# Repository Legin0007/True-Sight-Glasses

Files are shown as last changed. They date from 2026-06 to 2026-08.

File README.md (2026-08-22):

## What this project does
This project looks at people's faces using a small camera attached to the glasses frame. If a face matches an entry in my repository, the system retrieves the file name and plays the audio through a small speaker into my ear. Also I would like to preface this by saying I am using a libary called ESP-WHO and the example code I am using is made by them and modified by me. Also here is the demo video https://youtube.com/shorts/fBa7BR6LM4Y?is=uIni2kENnGARo2fe
# Why I made this
This project was made because I have a poor memory and I often forget peoples names so this is a simple and semi-elegant solution.Other people that may use this are people with memory loss or other memory related illnesses or diseases. 
# Challenges I faced
When I was designing this I went through 3 versions of my build. The first design was replaced because the chip I was using was too big and ended up with 2 separate parts which wasn't optimal so I changed the chip and battery to be smaller and fit on one side but I had to change that because it wasn't compatible with the code so the final design uses a esp32-s3 Eye which led to it being wider than the 2nd design.
## Construction Instructions:
### Sourcing Parts
1.Download the BOM and open it in google sheets or some thing like it.
2.Go through all the links and buy the parts that are required.
3.Download the folder called "3D-Models" download them and print them using your respective slicer.
4.After you source all the parts put them in their respective positions and use the pins to hold them in place.
### Soldering parts
1.Solder the battery positive to B+ and the negative to the B-
2.Solder 2 wires to out- and 1 to out+
3.Solder the out+ wire to one side of the switch and solder 2 wires on the output of the switch
4.Solder one of the positive wires from the switch to the amp SD pin.
5.On the amp make a wire from Vin to SD along with the positive wire.
6.Solder from the amp BCLK to IO21 then then LRC to IO48 then DIN to IO47
7.Solder the one remaining positive and negative wire to the 2 + and - pins on the back of the esp32-s3 eye to provide power to that.
### Flashing the firmware
1.You need to download the folder labeled "Code".
2.Open VS code and go to file and select open folder then go to esp-who\examples\human_face_recognition and click open folder.
3.You need to install ESP-IDF from the link in Resources and select custom install then follow all the steps until it asks for the version which you select 5.5.4 and continue with the installation.
4.Go to VS code and install the ESP-IDF extension.
5.Press F1 and type  ESP-IDF: Open ESP-IDF Terminal then type idf.py reconfigure
6.Press F1 and type  ESP-IDF: Select Port to Use (COM, tty, usbserial)
7.Press F1 and run ESP-IDF: Build, Flash and Start a Monitor
8.Go to the file who_recognition.cpp then you need to find where it says "Hello Amma" and change it out with the first person you will enroll so on and so forth.
## Note
The parts are held in place by having a gap in the main body which is can be filled by a seperate pin which blocks the parts from moving.  
## Bom

| Name | Description | Quanity | Unit Price | Shipping cost |
|---|---|---|---|---|
| Esp32s3-EYE | Camera and for running the code | 1 | 45 | 0 |
| Lipo 3.7V 500mAh battery | For powering all parts of the project | 1 | 8.59 | 3.26 |
| Bone Conduction Speaker  | To play peoples names | 1 | 2.16 | 0 |
| Adafruit Mono Amp | gives the speaker instructions | 1 | 2.64 | 0 |
| On/Off Switch | To enable and disable the power. | 1 | 2.81 | 0 |
| 3.3v ldo regulator | To make the volatage 3.3V | 1 | 1.85 | 0 |
| Soldering iron | To attach wires to other parts | 1 | 2.75 | 0 |
| Solder | Melted metal to attach wires | 1 | 2.91 | 0 |
| Heatshrink Tubing | Can cover wires for safety and looks | 1 | 2.68 | 0 |
| Wires | To connect all electrical parts together | 1 | 1.5 | 0 |
| Wire Stripper | To remove plastic from wires for easy soldering | 1 | 3.43 | 0 |
| TP4056 charging module | To recharge the battery | 1 | 5.99 | 0 |
| Total Cost | The total cost of all items | 1 | 91.24 | 0 |

## Wiring Plan



## Zine



## Render

Nigels First numero 1
True_Sight2

## Cad




## IRL Images

WhatsApp Image 2026-08-18 at 8 24 54 PM (2)

WhatsApp_Image_2026-08-18_at_8 24 54_PM-removebg-preview

## Resources
## Video 

https://youtube.com/shorts/fBa7BR6LM4Y?is=uIni2kENnGARo2fe
Download link 
https://docs.espressif.com/projects/idf-im-ui/en/latest/
ESP-WHO link 
https://developer.espressif.com/blog/2026/05/esp-who-get-started/

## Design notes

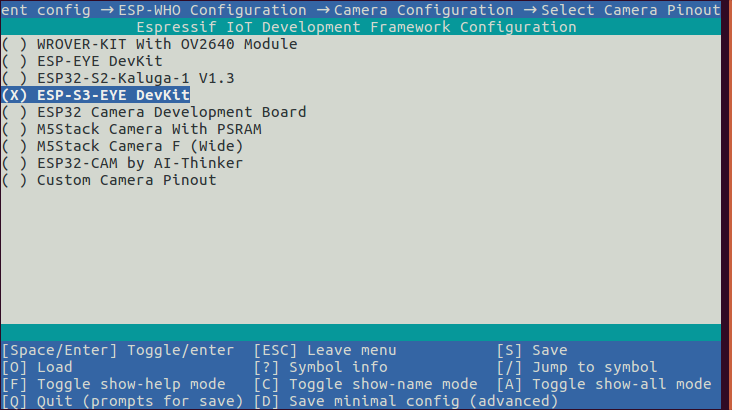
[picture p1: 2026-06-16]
Firmware/Source Code/esp-who/img/esp-who_config_camera_config_select_pinout.png

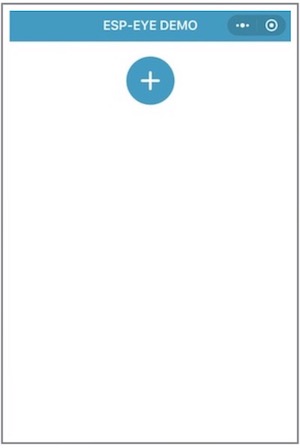
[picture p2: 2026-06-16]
Firmware/Source Code/esp-who/img/esp_eye_Wechat_cross.jpeg

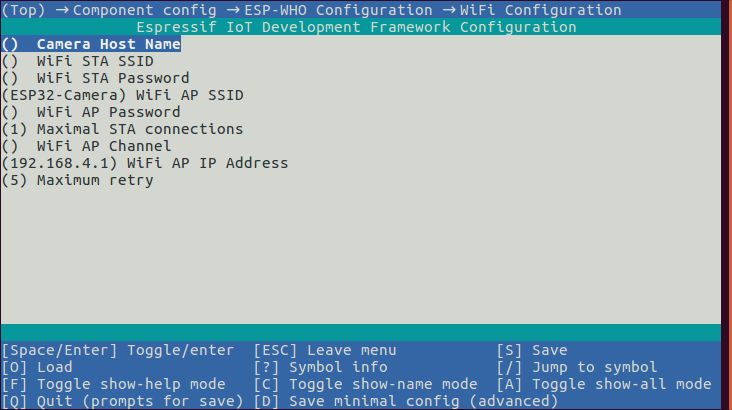
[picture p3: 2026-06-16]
Firmware/Source Code/esp-who/img/esp-who_config_wifi_config.png

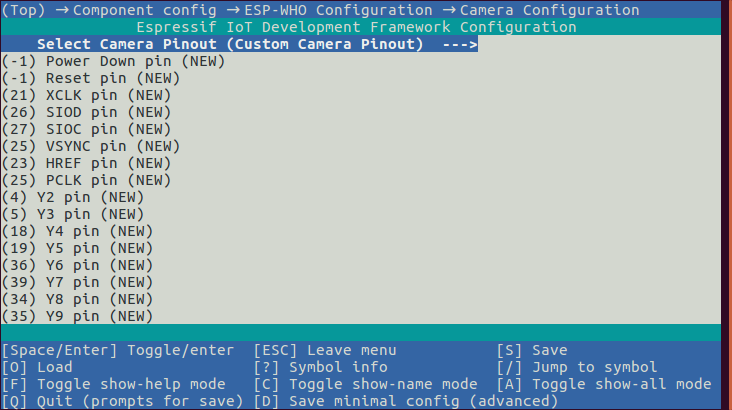
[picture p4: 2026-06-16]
Firmware/Source Code/esp-who/img/esp-who_config_camera_config_custom.png

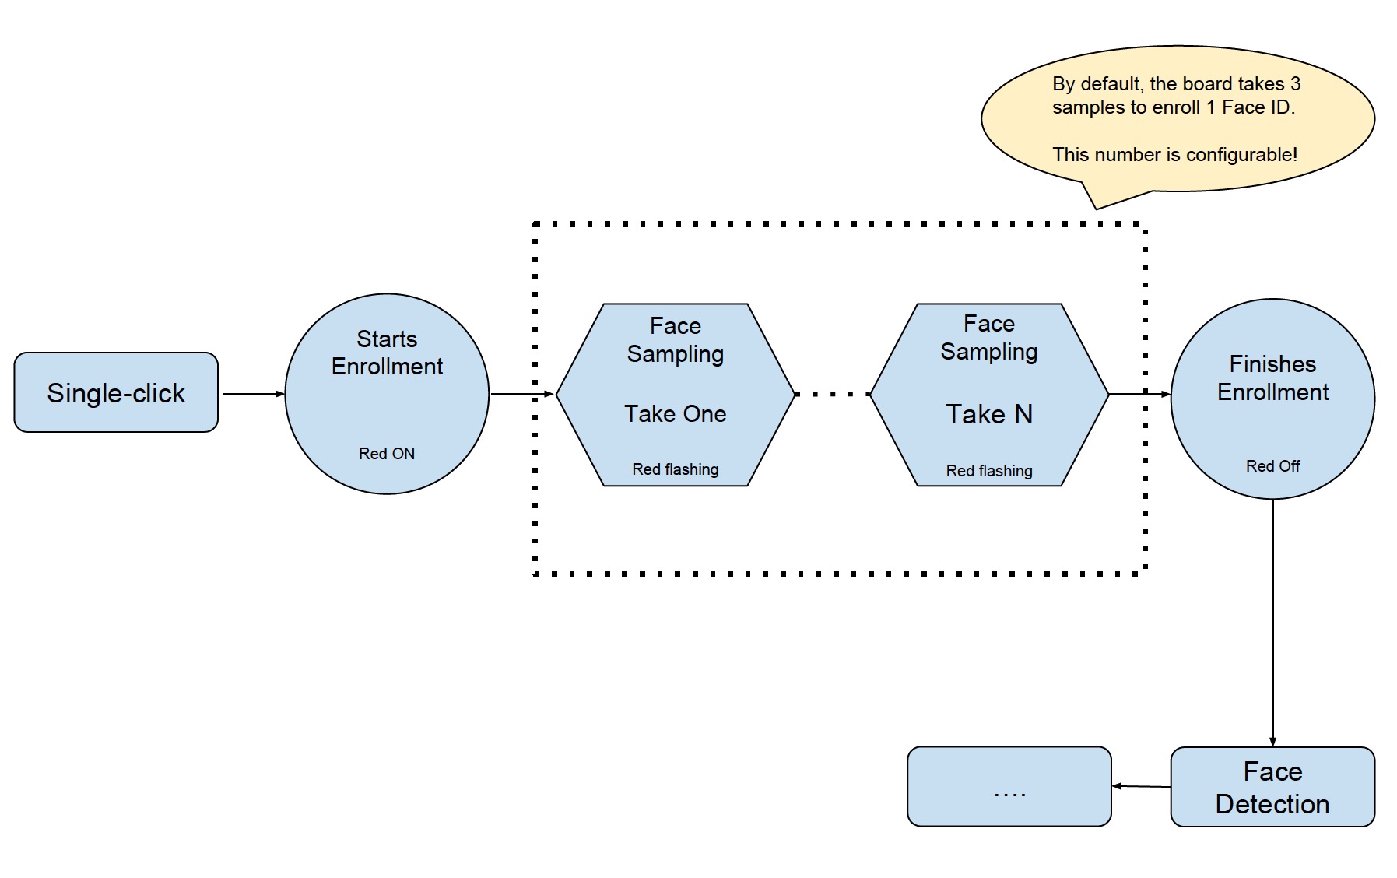
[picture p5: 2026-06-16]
Firmware/Source Code/esp-who/docs/_static/get-started/face_id_enrollment_en.png

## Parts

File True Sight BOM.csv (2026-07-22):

Name | Description | Quanity | Unit Price | Shipping cost | Total Price(With Shipping) | Running Total | Product Links | Notes
Esp32s3-EYE | Camera and for running the code | 1 | 45 | 0 | 45 | 47.98 | https://www.amazon.com/Espressif-ESP32-S3-EYE-Development-Board/dp/B09MS6PH7L | No notes
Lipo 3.7V 500mAh battery | For powering all parts of the project | 1 | 8.59 | 3.26 | 11.85 | 60.62 | https://www.amazon.com/801350-Lithium-Polymer-Battery-Rechargeable/dp/B0C2KSTN7Q | I used amazon for this so I can still have a 500mAh battery and have enough time to build
Bone Conduction Speaker | To play peoples names | 1 | 2.16 | 0 | 2.16 | 62.92 | https://www.aliexpress.us/item/3256809614716496.html?curPageLogUid=sKZA58d3EmLT | This has 5 speakers but I will only be using 1 and all of the others are more expensive with than this pack
Adafruit Mono Amp | gives the speaker instructions | 1 | 2.64 | 0 | 2.64 | 65.73 | https://www.aliexpress.us/item/3256811578520176.html?curPageLogUid=CChBUG9uadbR | This has different positioned pins than the one I have in my wiring plan but it seems that all of them are like this
On/Off Switch | To enable and disable the power. | 1 | 2.81 | 0 | 2.81 | 68.73 | https://www.aliexpress.us/item/3256807801613950.html?curPageLogUid=UmSibAmCQbCK | This product comes in packs of 5 as a minimum but I will only be using one the reason I picked this one is because it is very small
3.3v ldo regulator | To make the volatage 3.3V | 1 | 1.85 | 0 | 1.85 | 70.7 | https://www.aliexpress.us/item/2251801809976592.html?curPageLogUid=MLUUnN5VdEQj | Choose color MINI 3.3V-5PCS AND it is a pack of 5 but I only need one and this is the cheapest
Soldering iron | To attach wires to other parts | 1 | 2.75 | 0 | 2.75 | 73.63 | https://www.aliexpress.us/item/3256806912901320.html?curPageLogUid=uCbCUELEs9hH | I chose the color 7 in 1 blue EU because it is the same price and gives me some extra attachments but if the sale ends I will get the normal version
Solder | Melted metal to attach wires | 1 | 2.91 | 0 | 2.91 | 76.73 | https://www.aliexpress.us/item/3256807971607287.html?curPageLogUid=pQcrFQWQhYSq | Choose type 50 grams
Heatshrink Tubing | Can cover wires for safety and looks | 1 | 2.68 | 0 | 2.68 | 79.59 | https://www.aliexpress.us/item/3256808709374117.html?curPageLogUid=f3gYQKIKKTDA | Choose Color: 127PCS bags Black AND there are 120ish pieces of tubing and I wont use it all but it is the cheapest option availble
Wires | To connect all electrical parts together | 1 | 1.5 | 0 | 1.5 | 81.19 | https://www.aliexpress.us/item/3256804564161230.html?curPageLogUid=cpI5qmmXqlHe | Choose 24 AWG and 5 Meters Color white
Wire Stripper | To remove plastic from wires for easy soldering | 1 | 3.43 | 0 | 3.43 | 84.85 | https://www.aliexpress.us/item/3256811641376358.html?curPageLogUid=Qt32ucLM3CqE | I am not sure if I am allowed to buy this so this may be removed
TP4056 charging module | To recharge the battery | 1 | 5.99 | 0 | 5.99 | 91.24 | https://www.amazon.com/HiLetgo-Lithium-Charging-Protection-Functions/dp/B07PKND8KG | On amazon because I need it to come fast and there is 3 but I am only using 1
Total Cost | The total cost of all items | 1 | 91.24 | 0 | 0

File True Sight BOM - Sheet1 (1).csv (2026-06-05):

Name | Description | Quanity | Unit Price | Shipping cost | Total Price(With Shipping) | Product Links | Running Total | Notes
XIAO ESP32-S3 chip with sense expansion board | Camera and for running the code | 1 | 13 | 6.08 | 19.08 | https://www.seeedstudio.com/XIAO-ESP32S3-Sense-p-5639.html | 19.08 | Will arrive on 06/8/26 and I choose a sooner delivery option because otherwise I wouldn't have been able to finish in time. Used a one time 5$ off coupon
Lipo 3.7V 500mAh battery | For powering all parts of the project | 1 | 8.59 | 3.26 | 11.85 | https://www.amazon.com/801350-Lithium-Polymer-Battery-Rechargeable/dp/B0C2KSTN7Q | 31.72 | I used amazon for this so I can still have a 500mAh battery and have enough time to build
Bone Conduction Speaker | To play peoples names | 1 | 2.16 | 0 | 2.16 | https://www.aliexpress.us/item/3256809614716496.html?curPageLogUid=sKZA58d3EmLT | 34.02 | This has 5 speakers but I will only be using 1 and all of the others are more expensive with than this pack
Adafruit Mono Amp | gives the speaker instructions | 1 | 2.64 | 0 | 2.64 | https://www.aliexpress.us/item/3256811578520176.html?curPageLogUid=CChBUG9uadbR | 36.83 | This has different positioned pins than the one I have in my wiring plan but it seems that all of them are like this
On/Off Switch | To enable and disable the power. | 1 | 2.81 | 0 | 2.81 | https://www.aliexpress.us/item/3256807801613950.html?curPageLogUid=UmSibAmCQbCK | 39.83 | This product comes in packs of 5 as a minimum but I will only be using one the reason I picked this one is because it is very small
3.3v ldo regulator | To make the volatage 3.3V | 1 | 1.85 | 0 | 1.85 | https://www.aliexpress.us/item/2251801809976592.html?curPageLogUid=MLUUnN5VdEQj | 41.8 | Choose color MINI 3.3V-5PCS AND it is a pack of 5 but I only need one and this is the cheapest
Soldering iron | To attach wires to other parts | 1 | 2.75 | 0 | 2.75 | https://www.aliexpress.us/item/3256806912901320.html?curPageLogUid=uCbCUELEs9hH | 44.73 | I chose the color 7 in 1 blue EU because it is the same price and gives me some extra attachments but if the sale ends I will get the normal version
Solder | Melted metal to attach wires | 1 | 2.91 | 0 | 2.91 | https://www.aliexpress.us/item/3256807971607287.html?curPageLogUid=pQcrFQWQhYSq | 47.83 | Choose type 50 grams
Heatshrink Tubing | Can cover wires for safety and looks | 1 | 2.68 | 0 | 2.68 | https://www.aliexpress.us/item/3256808709374117.html?curPageLogUid=f3gYQKIKKTDA | 50.69 | Choose Color: 127PCS bags Black AND there are 120ish pieces of tubing and I wont use it all but it is the cheapest option availble
Wires | To connect all electrical parts together | 1 | 1.5 | 0 | 1.5 | https://www.aliexpress.us/item/3256804564161230.html?curPageLogUid=cpI5qmmXqlHe | 52.29 | Choose 24 AWG and 5 Meters Color white
Wire Stripper | To remove plastic from wires for easy soldering | 1 | 3.43 | 0 | 3.43 | https://www.aliexpress.us/item/3256811641376358.html?curPageLogUid=Qt32ucLM3CqE | 55.95 | I am not sure if I am allowed to buy this so this may be removed

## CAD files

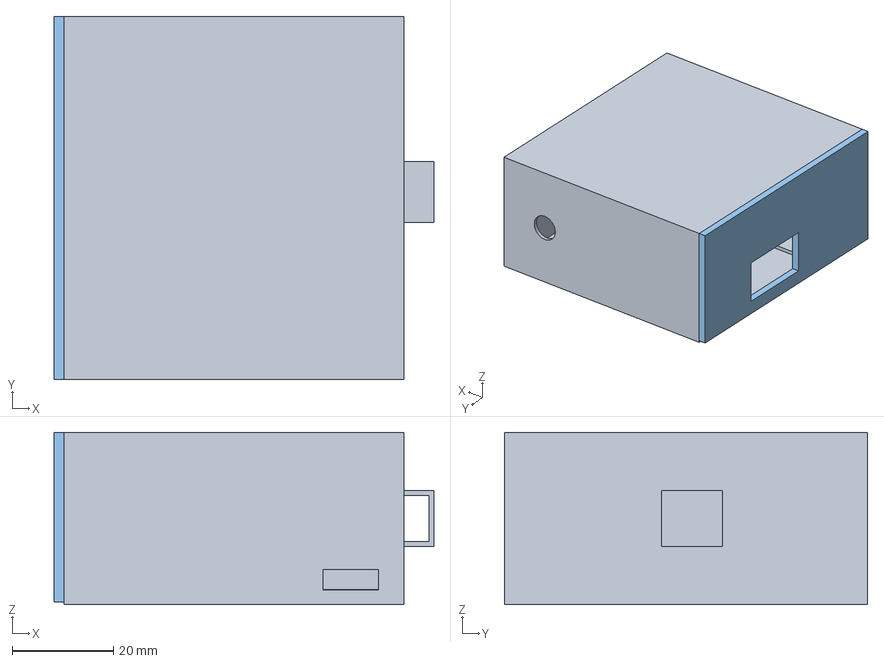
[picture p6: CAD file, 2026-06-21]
Fully Constructed/True_Sight_Fully_Constructed.step
74.9 x 71.6 x 34.0 mm

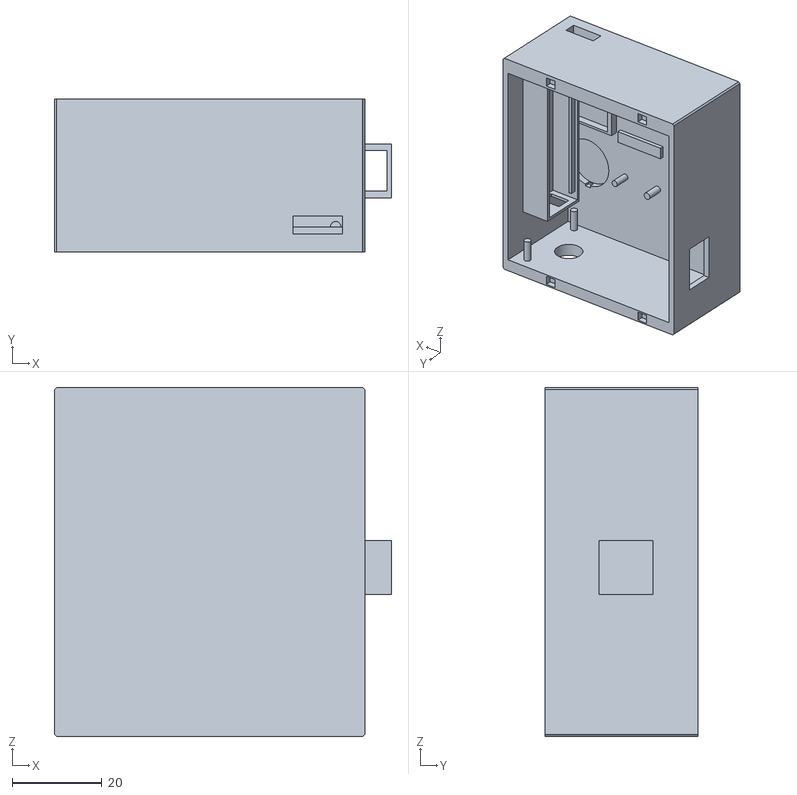
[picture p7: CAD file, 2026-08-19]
CAD/True_Sight_Fixed_Main_Body.stl
74.9 x 34.1 x 77.6

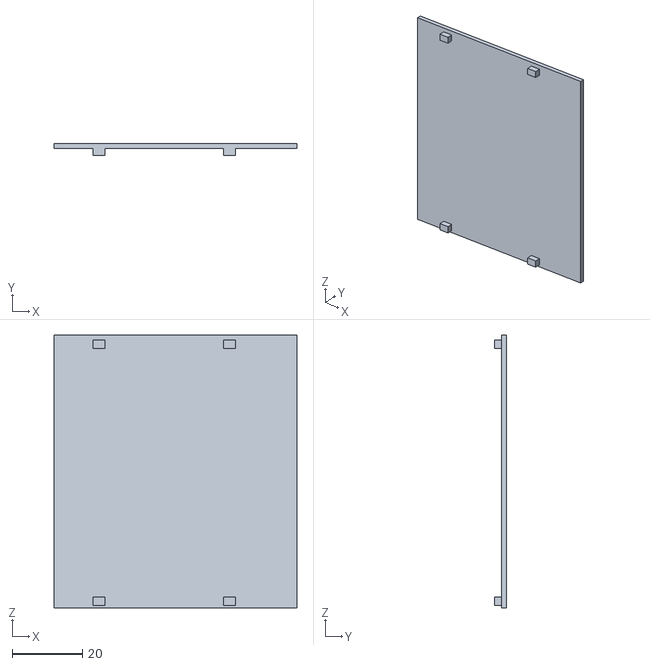
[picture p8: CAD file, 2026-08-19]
CAD/True_Sight_Fixed_Lid.stl
69.0 x 3.50 x 77.6

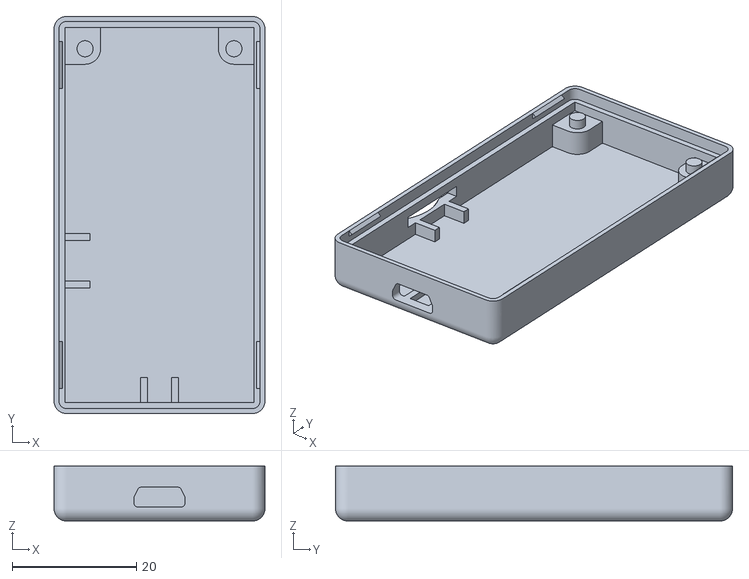
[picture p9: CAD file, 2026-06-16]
Firmware/Source Code/esp-who/docs/_static/get-started/ESP32-S3-EYE_3dpcase_btm.STL
34.0 x 64.0 x 8.86

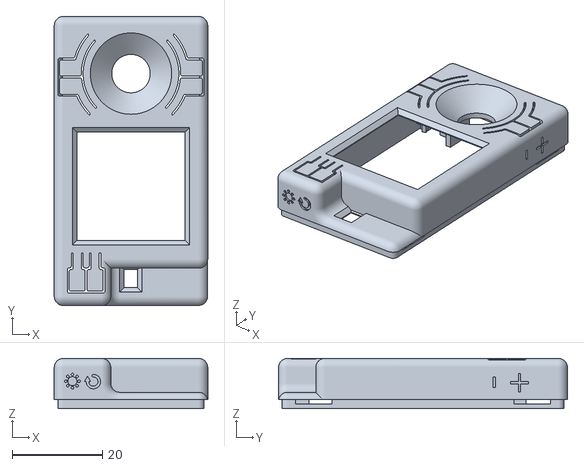
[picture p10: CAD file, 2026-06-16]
Firmware/Source Code/esp-who/docs/_static/get-started/ESP32-S3-EYE_3dpcase_top.STL
34.0 x 64.0 x 11.1

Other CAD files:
Fully Constructed/True_Sight_Fully_Constructed.stl

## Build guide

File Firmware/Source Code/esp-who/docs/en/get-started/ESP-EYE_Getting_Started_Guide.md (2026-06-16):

# ESP-EYE Getting Started Guide

[[中文]](../../zh_CN/get-started/ESP-EYE_Getting_Started_Guide.md)

**Note: The ESP-EYE board has reached End-of-Life (EOL). Please use the [ESP32-S3-EYE](./ESP32-S3-EYE_Getting_Started_Guide.md) as a replacement.**

## What You Need

* 1 × ESP-EYE V2.1 board
* 1 × Micro USB cable
* 1 × PC with Windows, Linux or Mac OS

## Overview

ESP-EYE is an ESP32-based development board that integrates a digital microphone, an 8 MB PSRAM and a 4 MB flash, while also providing an external 2-Megapixel camera. These features make the board ideal for applications relating to face detection, face recognition and speech recognition. Besides, the board can also support image transmission over Wi-Fi and debugging through a Micro USB port, which enables the development of advanced AI solutions.

## Hardware Preparation

The list and figure below describe the key components, interfaces and functions of the ESP-EYE development board:

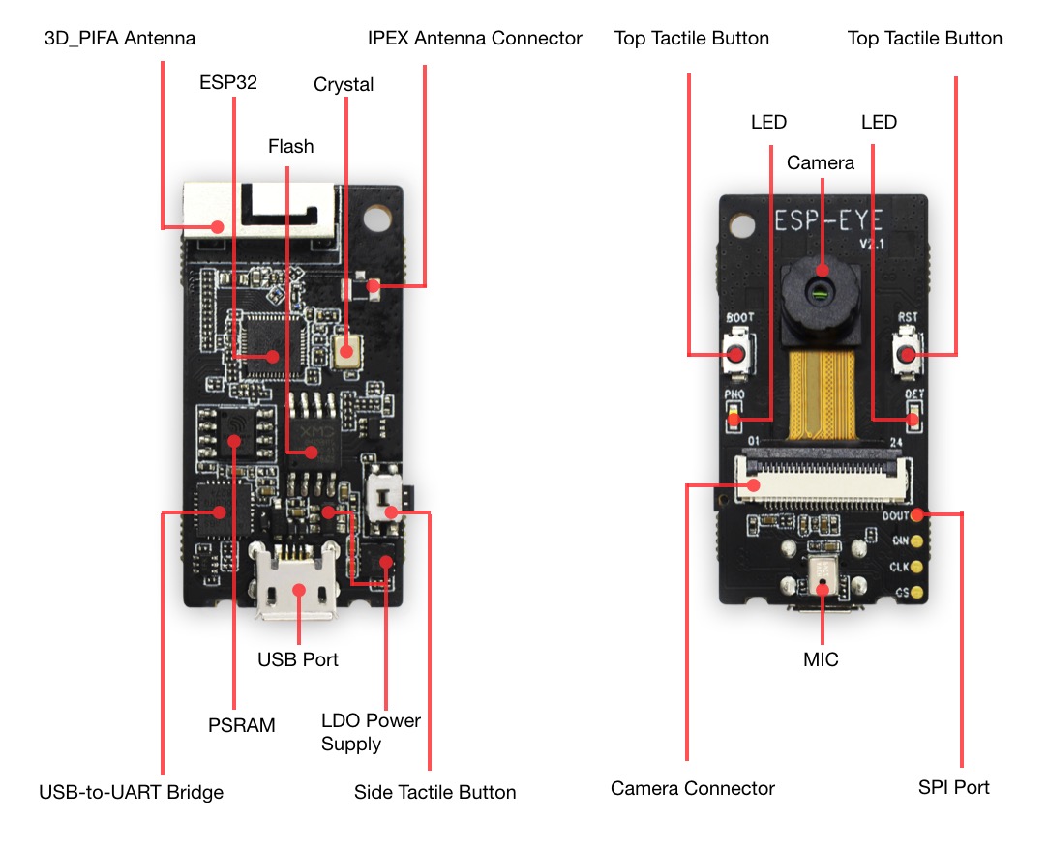
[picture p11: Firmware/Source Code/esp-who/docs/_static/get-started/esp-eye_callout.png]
ESP-EYE image


* **3D_PIFA Antenna**

	A 3D PIFA antenna. With the R14 resistor users can select the external IPEX antenna, whereas with the R15 resistor they can select the 3D antenna.

* **IPEX Connector**

	Used for connecting the external IPEX antenna. With the R14 resistor users can select the external IPEX antenna, whereas with the R15 resistor they can select the 3D antenna.
	
* **ESP32 Chip**

	A 2.4 GHz Wi-Fi and Bluetooth combo chip.
	
* **Crystal Oscillator**

	Provides an external clock to ESP32.

* **Flash & PSRAM**

	Provides memory for storing applications.

* **CP2102 USB-to-UART Chip**

	Converts the USB signals to UART signals.

* **USB Port**

	Provides power supply to the whole system.

* **LDO Power Supply**

	Provides the required power supply to the ESP32 chip, camera and LED indicators.

* **Side Tactile Button**

	A function key.

* **Top Tactile Button**

	Reset/Boot button. We recommend that you do not configure this button for other uses.

* **LED Indicators**

	The board has a red and a white indicator. Different flashing combinations of the red and white indicators reflect the different statuses of the board, e.g. waking up, networking, face detection, face recognition, face enrollment and face recognition.

* **Camera**

	An external 2-Megapixel camera module for face detection, face recognition and Face ID enrollment.

*  **Camera Connector**

	Used for connecting the external camera.

* **MIC**

	A digital microphone for voice control functions.

* **SPI Port**

	A reserved port for data transmission.

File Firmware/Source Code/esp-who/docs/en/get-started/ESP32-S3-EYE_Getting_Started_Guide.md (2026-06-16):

# ESP32-S3-EYE v2.2 <!-- omit in toc -->

[[中文]](../../zh_CN/get-started/ESP32-S3-EYE_Getting_Started_Guide.md)

- [1. Getting Started](#1-getting-started)
  - [1.1. Overview](#11-overview)
  - [1.2. Comparison with ESP-EYE](#12-comparison-with-esp-eye)
  - [1.3. Block Diagram](#13-block-diagram)
  - [1.4. Components on the ESP32-S3-EYE-MB Main Board](#14-components-on-the-esp32-s3-eye-mb-main-board)
  - [1.5. Components on the ESP32-S3-EYE-SUB Sub Board](#15-components-on-the-esp32-s3-eye-sub-sub-board)
  - [1.6. Contents and Packaging](#16-contents-and-packaging)
    - [1.6.1. Retail Orders](#161-retail-orders)
    - [1.6.2. Wholesale Orders](#162-wholesale-orders)
  - [1.7. Default Firmware and Function Test](#17-default-firmware-and-function-test)
- [2. Start Application Development](#2-start-application-development)
  - [2.1. Required Hardware](#21-required-hardware)
  - [2.2. Optional Hardware](#22-optional-hardware)
  - [2.3. Hardware Setup](#23-hardware-setup)
  - [2.4. Software Setup](#24-software-setup)
- [3. Hardware Reference](#3-hardware-reference)
  - [3.1. Notes on GPIO Allocations](#31-notes-on-gpio-allocations)
  - [3.2. Independent Module and Camera Power Supply](#32-independent-module-and-camera-power-supply)
- [4. Hardware Revision Details](#4-hardware-revision-details)
  - [4.1. Revision History](#41-revision-history)
  - [4.2. known Issues](#42-known-issues)
- [5. Related Documents](#5-related-documents)
  - [5.1. Datasheet](#51-datasheet)
  - [5.2. Schematic](#52-schematic)
  - [5.3. PCB Layout](#53-pcb-layout)
  - [5.4. Dimensions](#54-dimensions)
  - [5.5. 3D Printed Case](#55-3d-printed-case)

This user guide will help you get started with ESP32-S3-EYE v2.2 and will also provide more in-depth information.

> **Notice**
>
> If you use ESP32-S3-EYE v2.1, please follow this guide. The differences between v2.2 and v2.1 are described in Section [Hardware Revision Details](#4-hardware-revision-details).

The ESP32-S3-EYE is a small-sized AI development board produced by [Espressif](https://espressif.com). It is based on the [ESP32-S3](https://www.espressif.com/en/products/socs/esp32-s3) SoC and [ESP-WHO](https://github.com/espressif/esp-who), Espressif’s AI development framework. It features a 2-Megapixel camera, an LCD display, and a microphone, which are used for image recognition and audio processing. ESP32-S3-EYE offers plenty of storage, with an 8 MB Octal PSRAM and a 8 MB flash. It also supports image transmission via Wi-Fi and debugging through a Micro-USB port. With ESP-WHO, you can develop a variety of AIoT applications, such as smart doorbell, surveillance systems, facial recognition time clock, etc.

<center>

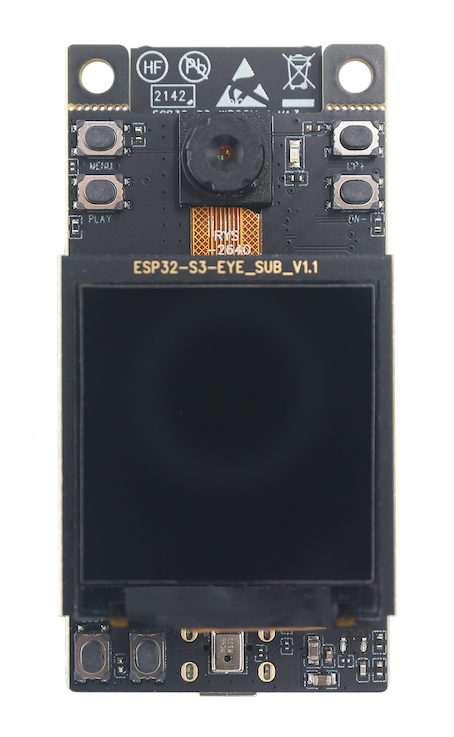
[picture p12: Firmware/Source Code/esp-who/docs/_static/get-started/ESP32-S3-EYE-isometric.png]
ESP32-S3-EYE
|  | 
|:--:| 
|ESP32-S3-EYE|

</center>

The document consists of the following major sections:

-   [Getting started](#1-getting-started): Introduction of the board, block diagram, description of key components, contents and packaging, as well as quick guide to use the board.
-   [Start Application Development](#2-start-application-development): Hardware and software setup instructions to flash firmware onto the board.
-   [Hardware Reference](#3-hardware-reference): More detailed information about the board's hardware.
-   [Hardware Revision Details](#4-hardware-revision-details): Hardware revision history, known issues, and links to user guides for previous versions (if any) of the board.
-   [Related Documents](#5-related-documents): Links to related documentation.

# 1. Getting Started

## 1.1. Overview

The ESP32-S3-EYE board consists of two parts: the main board (ESP32-S3-EYE-MB) that integrates the ESP32-S3-WROOM-1 module, camera, SD card slot, digital microphone, USB port, and function buttons; and the sub board (ESP32-S3-EYE-SUB) that contains an LCD display. The main board and sub board are connected through pin headers.

## 1.2. Comparison with ESP-EYE

The ESP32-S3-EYE has some additional functions comparing to [ESP-EYE](https://github.com/espressif/esp-who/blob/master/docs/en/get-started/ESP-EYE_Getting_Started_Guide.md), an ESP32-based development board. The comparison below covers key differences between the two boards:

| Feature | ESP32-S3-EYE | ESP-EYE | 
|---|---|---|
| Chip embedded | ESP32-S3 | ESP32 |
| PSRAM | 8 MB Octal PSRAM | 8 MB Quad PSRAM |
| Flash | 8 MB flash | 4 MB flash |
| LCD display | Yes | None |
| Accelerometer | Yes | None |
| Alternative power supply  | External battery (optional) | None |
| USB-to-UART bridge | No need. Functionality is provided by ESP32-S3 USB Serial/JTAG interface. | Yes |
| Antenna connector | No need. Antenna is provided by the ESP32-S3-WROOM-1 module. | Yes |

## 1.3. Block Diagram

The block diagram below presents main components of the ESP32-S3-EYE-MB main board (on the left) and the ESP32-S3-EYE-SUB sub board (on the right), as well as the interconnections between components.

<center>

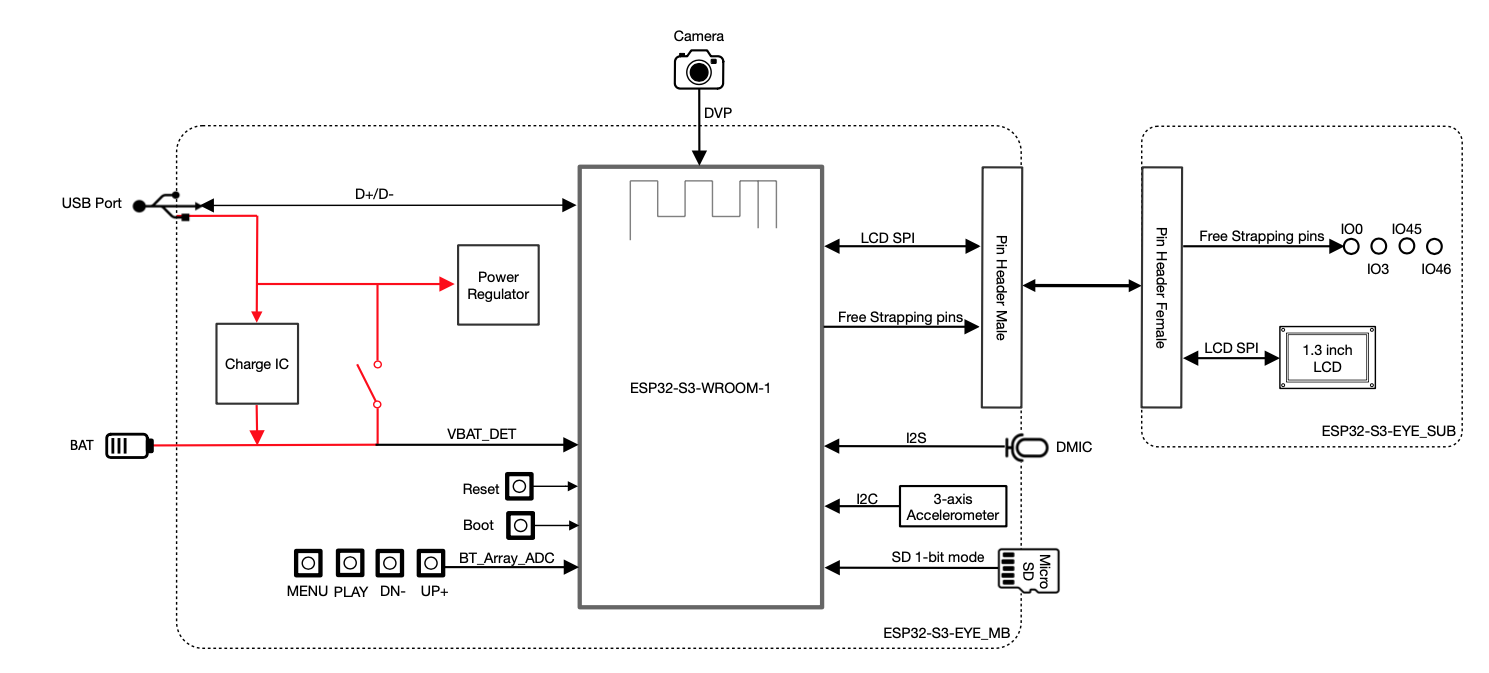
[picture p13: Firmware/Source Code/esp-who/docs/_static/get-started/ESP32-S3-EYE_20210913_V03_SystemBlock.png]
ESP32-S3-EYE Block Diagram
|  | 
|:--:| 
|ESP32-S3-EYE Block Diagram|

</center>

The following sections will describe the key components on the main board and the sub board, respectively.

## 1.4. Components on the ESP32-S3-EYE-MB Main Board

<center>

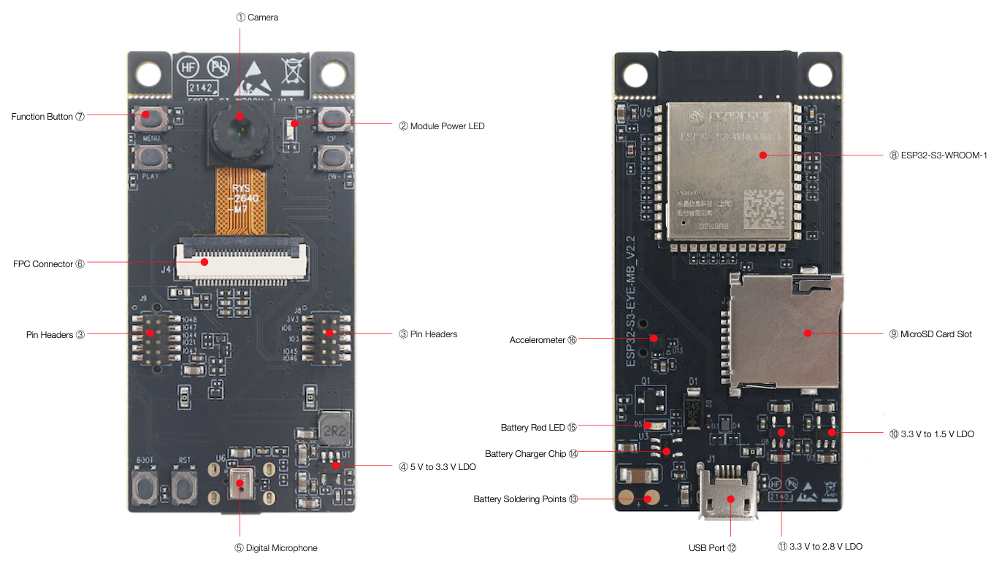
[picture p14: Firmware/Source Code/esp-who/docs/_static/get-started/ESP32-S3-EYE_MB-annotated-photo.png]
ESP32-S3-EYE-MB - front and back
|  | 
|:--:| 
|ESP32-S3-EYE-MB - front and back|

</center>

The key components of the board are described from front view to back view, starting from the camera, in an anti-clockwise direction.

| No. | Key Component | Description |
|-----|----|--|
| 1 | Camera | The camera [OV2640](https://github.com/espressif/esp32-camera) with 2 million pixels has a 66.5° field of view and a maximum resolution of 1600x1200. You can change the resolution when developing applications.|
| 2 | Module Power LED | The LED (green) turns on when USB power is connected to the board. If it is not turned on, it indicates either the USB power is not supplied, or the 5 V to 3.3 V LDO is broken. Software can configure GPIO3 to set different LED statuses (turned on/off, flashing) for different statuses of the board. Note that GPIO3 must be set up in open-drain mode. Pulling GPIO3 up may burn the LED.  |
| 3 | Pin Headers | Connect the female headers on the sub board.|
| 4 | 5 V to 3.3 V LDO | Power regulator that converts a 5 V supply into a 3.3 V output for the module.|
| 5 | Digital Microphone | The digital I2S MEMS microphone features 61 dB SNR and –26 dBFS sensitivity, working at 3.3 V.|
| 6 | FPC Connector | Connects the main board and the sub board. |
| 7 | Function Button | There are six function buttons on the board. Users can configure any functions as needed except for the RST button. |
| 8 | ESP32-S3-WROOM-1 | The ESP32-S3-WROOM-1 module embeds the ESP32-S3R8 chip variant that provides Wi-Fi and Bluetooth 5 (LE) connectivity, as well as dedicated vector instructions for accelerating neural network computing and signal processing. On top of the integrated 8 MB Octal SPI PSRAM offered by the SoC, the module also comes with 8 MB flash, allowing for fast data access. ESP32-S3-WROOM-1U module is also supported.|
| 9 | MicroSD Card Slot | Used for inserting a MicroSD card to expand memory capacity. |
| 10  | 3.3 V to 1.5 V LDO | Power regulator that converts a 3.3 V supply into a 1.5 V output for the camera.|
| 11  | 3.3 V to 2.8 V LDO | Power regulator that converts a 3.3 V supply into a 2.8 V output for the camera.|
| 12  | USB Port | A Micro-USB port used for 5 V power supply to the board, as well as for communication with the chip via GPIO19 and GPIO20.|
  13  | Battery Soldering Points | Used for soldering a battery socket to connect an external Li-ion battery that can serve as an alternative power supply to the board. If you use an external battery, make sure it has built-in protection circuit and fuse. The recommended specifications of the battery: capacity > 1000 mAh, output voltage 3.7 V, input voltage 4.2 V – 5 V.|
| 14  | Battery Charger Chip     | 1 A linear Li-ion battery charger (ME4054BM5G-N) in ThinSOT package. The power source for charging is the **USB Port**.|
| 15  | Battery Red LED          | When the USB power is connected to the board and a battery is not connected, the red LED blinks. If a battery is connected and being charged, the red LED turns on. When the battery is fully charged, it turns off.  |
| 16  | Accelerometer            | Three-axis accelerometer (QMA7981) for screen rotation, etc. |

## 1.5. Components on the ESP32-S3-EYE-SUB Sub Board

<center>

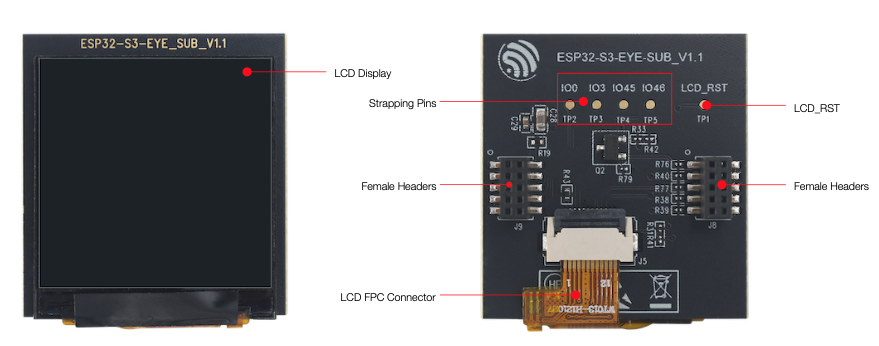
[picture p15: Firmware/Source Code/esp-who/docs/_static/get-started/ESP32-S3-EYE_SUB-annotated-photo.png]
ESP32-S3-EYE-SUB - front and back
|  | 
|:--:| 
|ESP32-S3-EYE-SUB - front and back|

</center>

The key components of the board are described from front view to back view, starting from the LCD display, in an anti-clockwise direction.

| Key Component | Description |
|---|----|
| LCD Display | 1.3” LCD display, connected to ESP32-S3 over the SPI bus. |
| Strapping Pins | Four strapping pins led out from the main board. They can be used as testing points. |
| Female Headers | Used for mounting onto the pin headers on the main board. |
| LCD FPC Connector  | Connects the sub board and the LCD display. |
| LCD_RST | LCD_RST testing point. You can use it to reset the LCD display with control signals.|

## 1.6. Contents and Packaging

### 1.6.1. Retail Orders

If you order a few samples, each board comes in an individual box. Each box contains:

-   1 x ESP32-S3-EYE-MB main board
-   1 x ESP32-S3-EYE-SUB sub board

The main board and sub board are assembled by default.

For retail orders, please go to <https://www.espressif.com/en/company/contact/buy-a-sample>.

### 1.6.2. Wholesale Orders

If you order in bulk, the boards come in large cardboard boxes.

For wholesale orders, please go to <https://www.espressif.com/en/contact-us/sales-questions>.

## 1.7. Default Firmware and Function Test

Each ESP32-S3-EYE board comes with pre-built [default firmware](https://github.com/espressif/esp-who/tree/master/default_bin/esp32-s3-eye) that allows you to test its functions including voice wake-up, voice command recognition, face detection and recognition.

To test the board's functions, you need the following hardware:

-   1 x ESP32-S3-EYE
-   1 x USB 2.0 cable (Standard-A to Micro-B), for USB power supply

Before powering up your board, please make sure that it is in good condition with no obvious signs of damage. Both the main board and the sub board should be firmly connected together. Then, follow the instructions described below:

1. Connect the board to a power supply through the **USB Port** using a USB cable. While the board is powered up, you will notice the following responses:

* The **Module Power LED** turns on for a few seconds, indicating that the default firmware is being loaded. 
* The **Module Power LED** turns off, indicating the default firmware has been loaded. The board enters human face recognition mode by default. 
* The LCD display shows live video streaming.

At this point, the board is ready for further instructions. You can control the board with either function buttons or voice commands. Function button control is described first:

2. Face the camera so whole human face is visible on the screen for the board to detect. Once a human face is detected, the board displays a blue rectangle.
3. Press **MENU** so that the board enters an ID (starting from 1) for a detected human face.
4. Press **UP+** so that the board starts face recognition. Once a face is recognized, the board displays the entered face ID. If it doesn’t know the face, it displays “WHO?”.
5. Press **PLAY** to delete the latest face ID. The board displays "XXX ID(S) LEFT".

To control the board with voice commands, follow the instructions below:

1. Complete step 1 described previously and notice responses from the board.
2. Activate the board with the default English wake word “Hi ESP”. When the wake word is detected, the **Module Power LED** will turn on, indicating that the board is ready for a speech command.
3. Say an English speech command to control the board. Once a speech command is recognized, the **Module Power LED** will blink. The supported English speech commands in face recognition mode are listed below:

| Default English Speech Commands | Response |
|---|---|
| Enter face | The board enters a human face ID. |
| Recognize face | The board displays a recognized human face ID, or "WHO?" for an unrecognized face. |  
| Delete face | The board deletes the latest human face ID entered and displays "XXX ID(S) LEFT". |

4. After waking up the board as described in step 2, you can also switch the board's working mode with speech commands. Once a speech command is recognized, the **Module Power LED** will blink.

| Speech Commands for Different Working Modes | Response |
|---|---|
| Face recognition | The board displays a blue rectangle if a human face is detected. |  
| Motion detection | The board displays a solid blue rectangle in upper-left corner if motion is detected. |
| Display only | The board displays only live video streaming. |
| Stop working | The board does nothing and displays Espressif logo. |

Now you get the first experience with the board. The following sections provide further information about how to flash firmware onto the board, configuration options, related resources, and more.

# 2. Start Application Development

This section provides instructions on how to do hardware/software setup and flash firmware onto the board for application development.

## 2.1. Required Hardware

-   1 x ESP32-S3-EYE
-   1 x USB 2.0 cable (Standard-A to Micro-B), for USB power supply and flashing firmware on to the board
-   1 x Computer running Windows, Linux, or macOS

## 2.2. Optional Hardware

-   1 x MicroSD card
-   1 x Li-ion battery
-   1 x [3D Printed case](#55-3d-printed-case)

> **Notice**
>
> Be sure to use a Li-ion battery that has built-in protection circuit.

## 2.3. Hardware Setup

Prepare the board for loading of the first sample application:
 
Connect the board with the computer through the **USB Port** using a USB cable. The **Module Power LED** should turn on. Assuming that a battery is not connected, the **Battery Red LED** will blink.

Now the board is ready for software setup.

## 2.4. Software Setup

After hardware setup, you can proceed with preparation of development tools. Go to the [guide to ESP-WHO](https://github.com/espressif/esp-who), which will walk you through the following steps:

1. [Get ESP-IDF](https://github.com/espressif/esp-who/#get-esp-idf) which provides a common framework to develop applications for ESP32-S3 in C language.
2. [Get ESP-WHO](https://github.com/espressif/esp-who/#get-esp-who) which is an image processing platform that runs on ESP-IDF.
3. [Run Examples](https://github.com/espressif/esp-who/#run-examples) that are provided by ESP-WHO.

# 3. Hardware Reference

This section provides more detailed information about the board's hardware.

## 3.1. Notes on GPIO Allocations

Except for GPIO3 that can be used to configure LED statuses, all GPIOs of the **ESP32-S3-WROOM-1** module have already been used to control specific components or functions of the board. If you would like to configure any pins yourself, please refer to the schematics provided in Section [Related Documents](#5-related-documents).

## 3.2. Independent Module and Camera Power Supply

The ESP32-S3-EYE board features independent power supplies to the camera and the remaining components. This should reduce noise in the audio signal from module components and improve overall performance of the components.

<center>

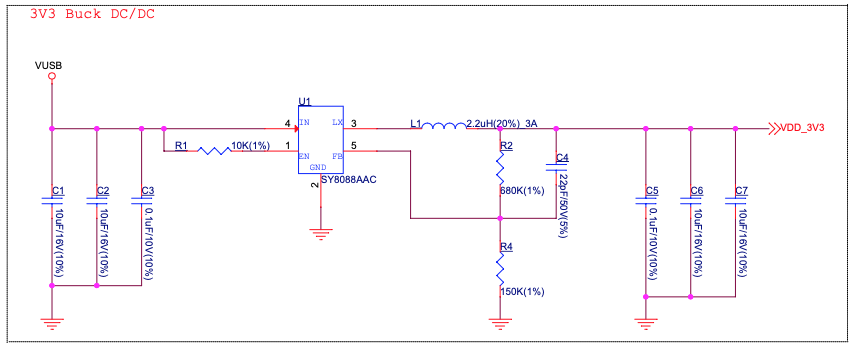
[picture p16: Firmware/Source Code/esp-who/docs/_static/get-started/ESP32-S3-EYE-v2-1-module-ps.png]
ESP32-S3-EYE - Module Power Supply
|| 
|:--:| 
|ESP32-S3-EYE - Module Power Supply|

</center>

<center>

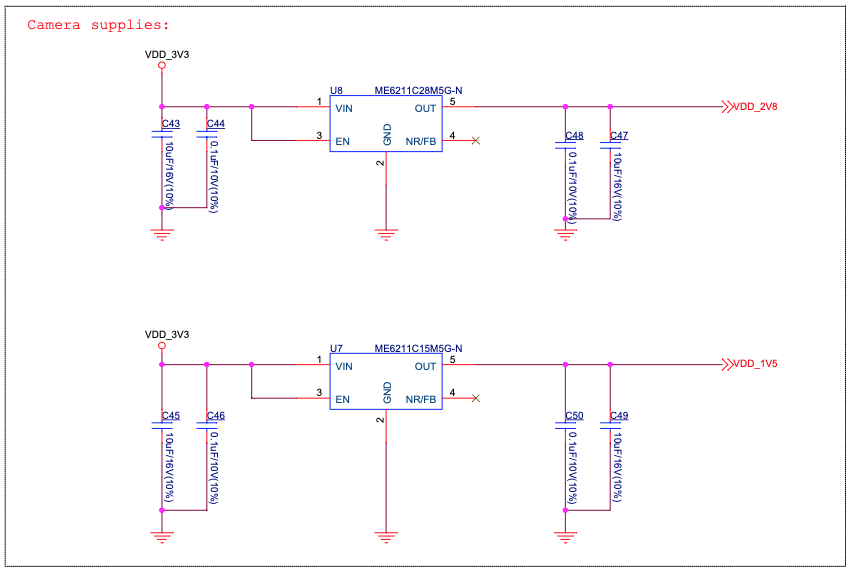
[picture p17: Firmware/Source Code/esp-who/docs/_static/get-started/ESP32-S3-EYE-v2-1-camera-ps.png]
ESP32-S3-EYE - Camera Power Supply
|| 
|:--:| 
|ESP32-S3-EYE - Camera Power Supplies|

</center>

# 4. Hardware Revision Details

## 4.1. Revision History

Compared to ESP32-S3-EYE v2.1, ESP32-S3-EYE v2.2 has two changes in hardware: 1) marking on the main board，2) additional current limiting resistor on the main board; and one change in firmware: additional support for English wake-up word and commands.

Changes in hardware are described in detail below:

1.  Marking on the (back of) main board: ESP32-S3-EYE v2.2 has marking "ESP32-S3-EYE-MB_V2.2" on the main board, while ESP32-S3-EYE v2.1 has marking "ESP32-S3-EYE-MB_V2.1" on the main board.

| ESP32-S3-EYE-MB_V2.2 Marking | ESP32-S3-EYE-MB_V2.1 Marking |
|---|----|
|  ESP32-S3-EYE-MB_V2.2 Marking |ESP32-S3-EYE-MB_V2.1 Marking |

2.  The current limiting resistor R83 is added to the ESP32-S3-EYE v2.2 main board to protect the **Module Power LED** from burning in case GPIO3 is pulled up.

| ESP32-S3-EYE v2.2 with R83 | ESP32-S3-EYE v2.1 Without R83  |
|---|----|
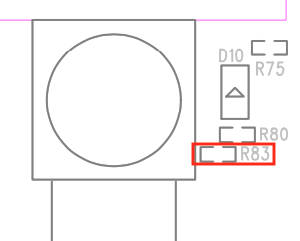
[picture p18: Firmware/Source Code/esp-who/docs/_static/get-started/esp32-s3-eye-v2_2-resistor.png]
ESP32-S3-EYE v2.2 with R83
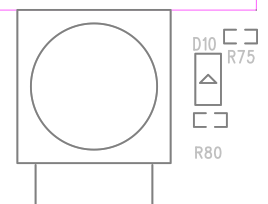
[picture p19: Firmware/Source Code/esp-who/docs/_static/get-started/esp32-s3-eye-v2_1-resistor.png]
ESP32-S3-EYE v2.1 Without R83
|   | |

3.  The **main board schematics**, **main board PCB layout diagrams**, **main board dimension diagrams**, **main board dimension source files** are updated because of the two hardware changes. (See [Related Documents](#5-related-documents)).

## 4.2. known Issues

ESP32-S3-EYE does not have a USB-to-UART bridge, which may cause a problem: If the program flashed onto the board keeps the chip rebooting, you cannot flash more programs onto the board.

In case this issue occurs, you need to:

- Hold down BOOT button and press RST button, then release RST button first, and BOOT button next. In this way, the board enters Firmware Download mode and you can start flashing program onto the board.
- After flashing the program, press RST button to start the program.

# 5. Related Documents

## 5.1. Datasheet

-   [ESP32-S3 Datasheet](https://www.espressif.com/sites/default/files/documentation/esp32-s3_datasheet_en.pdf) (PDF)
-   [ESP32-S3-WROOM-1 & ESP32-S3-WROOM-1U Datasheet](https://www.espressif.com/sites/default/files/documentation/esp32-s3-wroom-1_wroom-1u_datasheet_en.pdf) (PDF)

## 5.2. Schematic

-   [ESP32-S3-EYE-MB v2.2 Main Board Schematic](https://dl.espressif.com/dl/schematics/SCH_ESP32-S3-EYE-MB_20211201_V2.2.pdf) (PDF)
-   [ESP32-S3-EYE-MB v2.1 Main Board Schematic](https://dl.espressif.com/dl/schematics/SCH_ESP32-S3-EYE-MB_20210913_V2.1.pdf) (PDF)
-   [ESP32-S3-EYE-SUB Sub Board Schematic](https://dl.espressif.com/dl/schematics/SCH_ESP32-S3-EYE_SUB_V1.1_20210913.pdf) (PDF)

## 5.3. PCB Layout

-   [ESP32-S3-EYE-MB v2.2 Main Board PCB Layout](https://dl.espressif.com/dl/schematics/PCB_ESP32-S3-EYE_MB_V2.2_20211201.pdf) (PDF)
-   [ESP32-S3-EYE-MB v2.1 Main Board PCB Layout](https://dl.espressif.com/dl/schematics/PCB_ESP32-S3-EYE_MB_V2.1_20210913.pdf) (PDF)
-   [ESP32-S3-EYE-SUB Sub Board PCB Layout](https://dl.espressif.com/dl/schematics/PCB_ESP32-S3-EYE_SUB_V1.1_20210913.pdf) (PDF)

## 5.4. Dimensions

-   [ESP32-S3-EYE-MB v2.2 Main Board Front Dimensions](https://dl.espressif.com/dl/schematics/DXF_ESP32-S3-EYE_MB_top_V2.2_20211207.pdf) (PDF)
-   [ESP32-S3-EYE-MB v2.1 Main Board Front Dimensions](https://dl.espressif.com/dl/schematics/DXF_ESP32-S3-EYE_MB_top_V2.1_20211111.pdf) (PDF)
-   [ESP32-S3-EYE-MB v2.2 Main Board Back Dimensions](https://dl.espressif.com/dl/schematics/DXF_ESP32-S3-EYE_MB_Bottom_V2.2_20211207.pdf) (PDF)
-   [ESP32-S3-EYE-MB v2.1 Main Board Back Dimensions](https://dl.espressif.com/dl/schematics/DXF_ESP32-S3-EYE_MB_Bottom_V2.1_20211111.pdf) (PDF)
-   [ESP32-S3-EYE-SUB Sub Board Dimensions](https://dl.espressif.com/dl/schematics/DXF_ESP32-S3-EYE_SUB_V1.1_20211111.pdf) (PDF)
-   [ESP32-S3-EYE-MB v2.2 Main Board Front Dimensions Source File](https://dl.espressif.com/dl/schematics/DXF_ESP32-S3-EYE_MB_top_V2.2_20211207.dxf) (DXF) - You can view it with [Autodesk Viewer](https://viewer.autodesk.com/) online
-   [ESP32-S3-EYE-MB v2.1 Main Board Front Dimensions Source File](https://dl.espressif.com/dl/schematics/DXF_ESP32-S3-EYE_MB_top_V2.1_20211111.dxf) (DXF) - You can view it with [Autodesk Viewer](https://viewer.autodesk.com/) online
-   [ESP32-S3-EYE-MB v2.2 Main Board Back Dimensions Source File](https://dl.espressif.com/dl/schematics/DXF_ESP32-S3-EYE_MB_Bottom_V2.2_20211207.dxf) (DXF) - You can view it with [Autodesk Viewer](https://viewer.autodesk.com/) online
-   [ESP32-S3-EYE-MB v2.1 Main Board Back Dimensions Source File](https://dl.espressif.com/dl/schematics/DXF_ESP32-S3-EYE_MB_Bottom_V2.1_20211111.dxf) (DXF) - You can view it with [Autodesk Viewer](https://viewer.autodesk.com/) online
-   [ESP32-S3-EYE-SUB Sub Board Dimensions Source File](https://dl.espressif.com/dl/schematics/DXF_ESP32-S3-EYE_SUB_V1.1_20211111.dxf) (DXF) - You can view it with [Autodesk Viewer](https://viewer.autodesk.com/) online

## 5.5. 3D Printed Case

The following 3D model is a two-part case you can 3D print for your ESP32-S3-EYE. Do note that with all 3D Printed products, there will be a variance in tolerance and fitting. Your success may vary.

- [ESP32-S3-EYE Top Case](../../_static/get-started/ESP32-S3-EYE_3dpcase_top.STL)
- [ESP32-S3-EYE Bottom Case](../../_static/get-started/ESP32-S3-EYE_3dpcase_btm.STL)

<center>

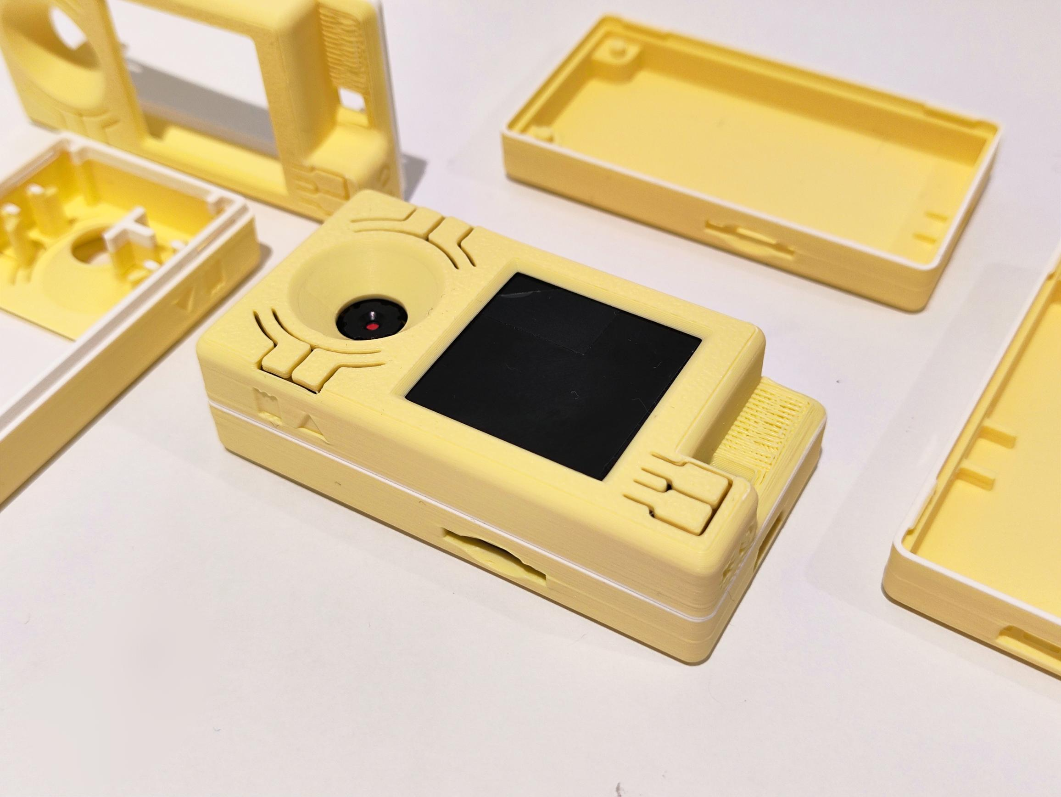
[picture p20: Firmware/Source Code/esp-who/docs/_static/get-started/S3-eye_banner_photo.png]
ESP32-S3-EYE - Case 3D printed on BambuLab P1S
|| 
|:--:| 
|ESP32-S3-EYE - Case 3D printed on [BambuLab P1S](https://bambulab.com/en/p1)|

</center>

For further design documentation for the board, please contact us at [<sales@espressif.com>](sales@espressif.com).

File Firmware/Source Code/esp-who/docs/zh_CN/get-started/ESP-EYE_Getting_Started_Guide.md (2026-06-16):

# ESP-EYE 入门指南

[[EN]](../../en/get-started/ESP-EYE_Getting_Started_Guide.md)

**Note: ESP-EYE 已经停止维护。请使用 [ESP32-S3-EYE](./ESP32-S3-EYE_Getting_Started_Guide.md)。**

## 准备工作

* 1 × ESP-EYE V2.1 开发板
* 1 × Micro USB B 电缆
* 1 × PC（Windows、Linux 或 Mac OS）

## 简介

ESP-EYE 是一款面向人脸识别和语音识别市场的开发板，搭载 ESP32 芯片、200 W 像素摄像头、数字麦克风、8 MB PSRAM 和 4 MB Flash，可满足各种 AI 应用开发需求。此外，该开发板还支持 Wi-Fi 图像传输、Micro USB 调试和供电，可以实现语音唤醒、人脸检测与识别等功能，可协助用户开发高度集成的 AI 解决方案。

## 硬件组成

ESP-EYE 开发板的产品图请见下方：

ESP-EYE image

具体包括以下硬件组成：

* **3D_PIFA Antenna（3D_PIFA 天线）**

	3D PIFA 天线。用户可通过选贴 R14/R15 电阻，选用 3D 天线（选贴 R15）或外接 IPEX 天线（选贴 R14）。

* **IPEX Connector（IPEX 连接器）**

	用于外接 IPEX 天线。用户可通过选贴 R14/R15 电阻，选用 3D 天线（选贴 R15）或外接 IPEX 天线（选贴 R14）。

* **ESP32 Chip（ESP32 芯片）**

	集成 2.4 GHz Wi-Fi 和蓝牙双模的单芯片。

* **Crystal（晶振）**

	ESP32 的外部晶振时钟源。

* **Flash & PSRAM**

	存储芯片，用于储存程序。

* **CP2102 USB-UART Chip（USB 转 UART 芯片）**

	实现 USB 到 UART 的转换功能。

* **USB Port（USB 供电接口）**

	为整个系统供电。

* **LDO Power Supply（LDO 供电芯片）**

	为 ESP32 芯片、摄像头、LED 指示灯等部件提供各自所需的电压。

* **Side Tactile Button（侧面轻触按键）**

	功能按键。

* **Top Tactile Button（正面轻触按键）**

	用于 ESP32 的 RST（复位）、BOOT（下载），不建议设置他用。

* **LED 指示灯**

	红灯和白灯各一个，可用于指示唤醒、联网、人脸检测、人脸录入、人脸识别等不同过程中的状态。

* **Camera（摄像头）**

	实现检测识别等功能。

* **Camera Connector（摄像头连接器）**

	用于外接摄像头模块。

* **MIC（麦克风）**

	数字型麦克风，实现语音控制功能。

* **SPI Port（SPI 接口）**

	预留数据传输接口。

## 软件开发

ESP-EYE 可在 Linux、MacOs、Windows 操作系统中完成软件烧写。目前，必须进行开发环境的工具链配置，详见下方介绍。

### 准备工作

- 阅读 [ESP-IDF编程指南](https://docs.espressif.com/projects/esp-idf/zh_CN/v3.1.1/get-started/index.html)，参考相应章节，配置工具链；
- 准备 Micro USB 线，用于连接 PC 和 ESP-EYE 开发板；
- 选择一款适合开发环境的工具，例如 Terminal (Linux/MacOS) 或 MinGW (Windows) 等。

### 软件获取

打开终端（例如 Linux 环境下的 Terminal），将软件代码克隆到本地：

```
git clone --recursive https://github.com/espressif/esp-who.git 
```

执行以上命令会默认生成一个 `esp-who` 的文件夹。

> 注意不要忘记 `--recursive` 选项。如果你克隆 ESP-IDF 时没有带这个选项，你还需要运进入相应文件夹中，执行以下命令下载相应的子模块：
```
git submodule update --init --recursive
```

### 设置路径

请参考[设置路径](https://docs.espressif.com/projects/esp-idf/zh_CN/v3.1.1/get-started/index.html#get-started-setup-path)章节，将 `IDF_PATH` 设置为 `esp-who/esp-idf`。

### 软件烧写

下面，我们以 Linux 环境为例，介绍向 ESP-EYE 烧写程序的过程：

- 首先将 ESP-EYE 接入 PC，接入即上电；
- 通过命令 `ls /dev/ttyUSB*` 查看开发板是否成功接入 PC。成功接入后，列表将新增类似 `/dev/ttyUSB0` 的信息；
- 进入一个 example 工程文件中，例如 `cd esp-who/examples/single_chip/recognition_solution`；
- 执行 `make defconfig` 进行默认配置；
- 执行 `make menuconfig`，在 `Serial flasher config` 中设置 `Default serial port` 设备名称（与第二步查看的设备名称一致，一般设置为 `/dev/ttyUSB0`），保存退出；
- 执行 `make flash`，进行软件烧写。

### 终端获取日志

下面，我们以 Linux 环境为例，介绍如何查看日志：

- 打开终端；
- 执行 `make monitor`。

> 注意：这个过程会重启开发板。

### 交互功能

ESP-EYE 开发板的工作流程如下图所示：

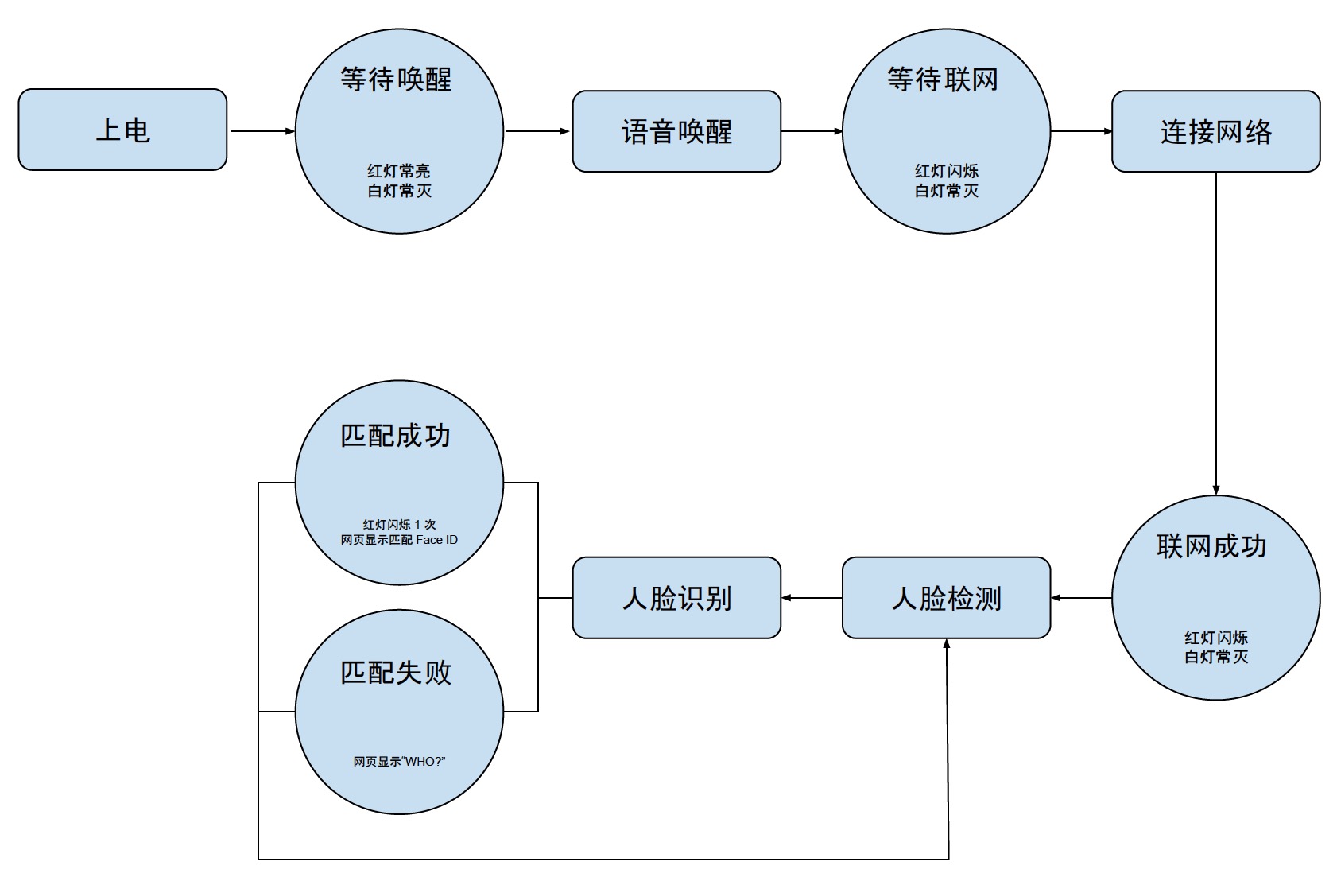
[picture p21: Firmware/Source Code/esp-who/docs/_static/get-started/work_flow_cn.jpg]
esp-eye-workflow


#### 1. 语音唤醒

开发板上电后，会进入“等待唤醒”状态（红灯常亮、白灯常灭），需要用户通过语音进行唤醒。支持“Hi 乐鑫”唤醒，当用户说出“Hi 乐鑫”的唤醒词后，开发板唤醒并进入“等待联网”状态（红灯闪烁，白灯常灭）。此时，用户可进行联网操作。  

#### 2. 连接网络

用户可通过 PC、手机等设备，连接 ESP-EYE 创建的 Wi-Fi 热点。该热点的默认信息如下：

- 用户名：esp-eye-xxxx（xxxx 为设备 MAC 地址）
- 密码：无需密码

用户也可通过如下方式，自行设置用户名和密码：  

- 打开终端；
- 执行 `make menuconfig`，并按照下图进行设置：

	wifi connection

> 注：用户重新设置 Wi-Fi 热点的用户名和密码后，需要重新进行软件烧录。

#### 3. 人脸检测

联网成功后，ESP-EYE 会进行“人脸检测”。用户可以打开浏览器，输入地址 `192.168.4.1/face_stream`，在网页上即可看到实时图像信息。此时，开发板红灯熄灭、白灯常亮。

#### 4. 人脸识别

当开发板检测到人脸时，如已存在录入的 Face ID，则开发板将进行“人脸识别”：

- “人脸识别”匹配成功 -- 开发板红灯闪烁 1 次，网页显示 **HELLO ID XXX**
- “人脸识别”匹配失败 -- 开发板无反应，网页显示 **WHO?**”

否则，开发板仅进行“人脸检测”。此时，若用户希望使用人脸识别功能，则请首先录入至少一个 Face ID。  

#### 5. 人脸录入与删除

在联网成功的前提下，可通过摄像头采集人脸，录入 Face ID。

##### 5.1 录入 Face ID

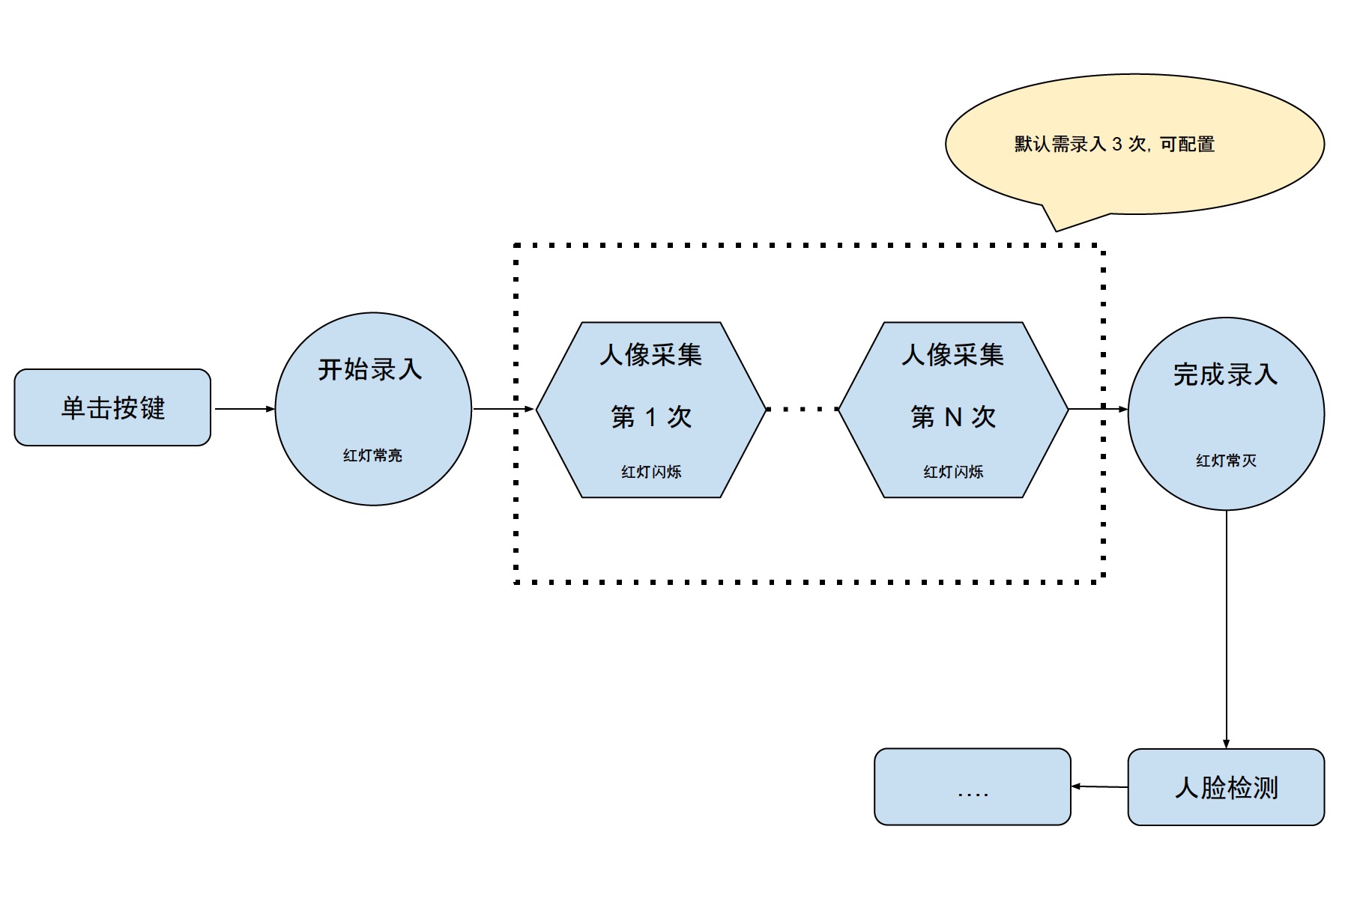
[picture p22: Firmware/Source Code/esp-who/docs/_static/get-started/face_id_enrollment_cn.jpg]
录入 Face ID


- 用户单击侧面轻触按键，可进入“录入 Face ID”（红灯常亮），网页显示: **START ENROLLING**；
- 用户面对摄像头，开始采集人像。每次成功一次采集，开发板将红灯闪烁，网页显示对应的采集次数，比如 **THE 1st SAMPLE** 等。默认情况下，用户每录入一个 Face ID 需要采集 3 次人像（可配置）。在人像采集过程中，如果红灯长时间未闪烁，建议用户调整姿态和角度，然后再试；
- 人像采集完成后，开发板红灯常灭，表明已完成录入该 Face ID。此时，网页显示：**ENROLLED FACE ID xxx**；
- Face ID 录入成功后，系统将返回“人脸检测”。

目前，ESP-EYE 开发板默认可录入 10 个 Face ID（可配置，具体与用户的 flash 内存分配有关）。

##### 5.2 删除 Face ID

- 用户单击表面BOOT按键，进入“删除 FACE ID”；
- 双击后，开发板白灯闪烁，系统将自动删除系统中存在的最早一条 FACE ID，终端显示：**XXX ID(S) LEFT**。

#### 异常情况

当出现“网络断开”或“联网超时”等异常情况时，开发板会回到“等待唤醒”状态。

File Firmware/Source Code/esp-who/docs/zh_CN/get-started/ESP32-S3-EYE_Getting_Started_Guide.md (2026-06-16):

# ESP32-S3-EYE v2.2 <!-- omit in toc -->

[[English Version]](../../en/get-started/ESP32-S3-EYE_Getting_Started_Guide.md)

- [1. 入门指南](#1-入门指南)
  - [1.1. 概述](#11-概述)
  - [1.2. ESP32-S3-EYE 与 ESP-EYE](#12-esp32-s3-eye-与-esp-eye)
  - [1.3. 功能框图](#13-功能框图)
  - [1.4. ESP32-S3-EYE-MB 主板组件](#14-esp32-s3-eye-mb-主板组件)
  - [1.5. ESP32-S3-EYE-SUB 子板组件](#15-esp32-s3-eye-sub-子板组件)
  - [1.6. 内含组件和包装](#16-内含组件和包装)
    - [1.6.1. 零售订单](#161-零售订单)
    - [1.6.2. 批量订单](#162-批量订单)
  - [1.7. 默认固件和功能测试](#17-默认固件和功能测试)
- [2. 开始开发应用](#2-开始开发应用)
  - [2.1. 必备硬件](#21-必备硬件)
  - [2.2. 可选硬件](#22-可选硬件)
  - [2.3. 硬件设置](#23-硬件设置)
  - [2.4. 软件设置](#24-软件设置)
- [3. 硬件参考](#3-硬件参考)
  - [3.1. GPIO 分配](#31-gpio-分配)
  - [3.2. 独立的模组与摄像头供电电路](#32-独立的模组与摄像头供电电路)
- [4. 硬件版本](#4-硬件版本)
  - [4.1. 改版历史](#41-改版历史)
  - [4.2. 已知问题](#42-已知问题)
- [5. 相关文档](#5-相关文档)
  - [5.1. 技术规格书](#51-技术规格书)
  - [5.2. 原理图](#52-原理图)
  - [5.3. PCB 布局图](#53-pcb-布局图)
  - [5.4. 尺寸图](#54-尺寸图)
  - [5.5. 3D打印外壳](#55-3D打印外壳)

本指南将帮助您快速上手 ESP32-S3-EYE v2.2，并提供该款开发板的详细信息。

> **注意**
>
> 如果您使用的是 ESP32-S3-EYE v2.1，请参考本指南。v2.2 相对 v2.1 的变化在[硬件版本](#4-硬件版本)小节中列出。

ESP32-S3-EYE 是[乐鑫](https://www.espressif.com/zh-hans/home)推出的一款小型 AI（人工智能）开发板，搭载 [ESP32-S3](https://www.espressif.com/zh-hans/products/socs/esp32-s3) 芯片和乐鑫 AI 开发框架 [ESP-WHO](https://github.com/espressif/esp-who/blob/master/README_CN.md)。开发板配置一个 2 百万像素的摄像头、一个 LCD 显示屏和一个麦克风，适用于图像识别和音频处理等应用。板上还配有 8 MB 八线 PSRAM 和 8 MB flash，具有充足的存储空间。此外，ESP32-S3 芯片还为开发板提供了 Wi-Fi 图传和 USB 端口调试等功能。您可以使用 ESP-WHO 开发各种 AIoT（人工智能物联网）应用，例如智能门铃、监控系统、人脸识别打卡机等。

<center>

| ESP32-S3-EYE | 
|:--:| 
|ESP32-S3-EYE|

</center>

本指南包括如下内容：

-  [入门指南](#1-入门指南)：介绍了开发板的功能和特性、组件、包装，以及如何快速使用开发板。
-  [开始开发应用](#2-开始开发应用)：说明了开发板烧录固件需要的硬件设置和软件设置。
-  [硬件参考](#3-硬件参考)：详细介绍了开发板的硬件。
-  [硬件版本](#4-硬件版本)：介绍硬件历史版本和已知问题，并提供链接至历史版本开发板的入门指南（如有）。
-  [相关文档](#5-相关文档)：列出了相关文档的链接。

# 1. 入门指南

## 1.1. 概述

ESP32-S3-EYE 开发板包含两部分：一块主板 ESP32-S3-EYE-MB，配置 ESP32-S3-WROOM-1 模组、摄像头、SD 卡槽、数字麦克风、USB 接口和功能按键等；一块子板 ESP32-S3-EYE-SUB，配置 LCD 显示屏等。主板和子板通过排针连接。

## 1.2. ESP32-S3-EYE 与 ESP-EYE

ESP32-S3-EYE 相比 [ESP-EYE](https://github.com/espressif/esp-who/blob/master/docs/zh_CN/get-started/ESP-EYE_Getting_Started_Guide.md) 支持更多功能。下表列出了两款开发板的主要不同之处：

| 特性 | ESP32-S3-EYE | ESP-EYE | 
|---|---|---|
| 内置芯片 | ESP32-S3 | ESP32 |
| PSRAM | 8 MB 八线 PSRAM | 8 MB 四线 PSRAM |
| Flash | 8 MB flash | 4 MB flash |
| LCD 显示屏 | 有 | 无 |
| 加速度传感器 | 有 | 无 |
| 可选电源  | 外接锂电池 | 无 |
| USB 至 UART 桥接器 | 不需要，由 ESP32-S3 USB Serial/JTAG 接口提供 | 需要 |
| 天线连接器 | 不需要，由 ESP32-S3-WROOM-1 模组提供 | 需要 |

## 1.3. 功能框图

功能框图显示了主板 ESP32-S3-EYE-MB（左侧） 和子板 ESP32-S3-EYE-SUB（右侧）的主要组件，以及组件之间的连接方式。

<center>

| ESP32-S3-EYE 功能框图 | 
|:--:| 
|ESP32-S3-EYE 功能框图|

</center>

下面分别介绍主板和子板上的主要组件。

## 1.4. ESP32-S3-EYE-MB 主板组件

<center>

| ESP32-S3-EYE-MB - 正面和背面 | 
|:--:| 
|ESP32-S3-EYE-MB - 正面和背面|

</center>

下面从摄像头开始依次介绍主板正面和背面的主要组件。

| 序号 | 主要组件| 介绍 |
|-----|----|--|
| 1 | Camera（摄像头） | [OV2640](https://github.com/espressif/esp32-camera) 摄像头，200 万像素，66.5° 视角，最高支持 1600x1200 分辨率。开发程序时可以配置分辨率。|
| 2 | Module Power LED（模组电源指示灯） | 开发板连接 USB 电源，模组电源指示灯绿灯亮起。如果绿灯不亮，则表示 USB 电源未接入，或者 **5 V 转 3.3 V LDO** 损坏。软件可以通过配置 GPIO3 为开发板的不同状态设置不同的 LED 灯组合状态（常亮/熄灭，闪烁等）。注意 GPIO3 必须配置为开漏模式，否则可能损坏 LED 灯。|
| 3 | Pin Headers（排针） | 连接子板的排母。|
| 4 | 5 V to 3.3 V LDO（5 V 转 3.3 V LDO） | 模组电路的电源转换器，输入 5 V，输出 3.3 V。|
| 5 | Digital Microphone（数字麦克风） | MEMS 数字麦，I2S 通信，灵敏度 -26 dBFS，SNR 61 dB，3V3 供电。|
| 6 | FPC Connector（FPC 接口） | 通过 FPC 排线连接主板和子板。 |
| 7 | Function Button（功能按键） | 板子上有 6 个功能按键，除了 RST 键不能配置，您可以配置其他 5 个按键的功能。 |
| 8 | ESP32-S3-WROOM-1 | ESP32-S3-WROOM-1 模组，内置 ESP32-S3R8 芯片，集成 Wi-Fi 和 Bluetooth 5 (LE) 子系统，还有专门的向量指令用于加速神经网络计算和信号处理。ESP32-S3R8 芯片叠封 8 MB PSRAM，模组还另外带有 8 MB flash，可灵活高效读取数据。开发板也兼容 ESP32-S3-WROOM-1U 模组。|
| 9 | MicroSD Card Slot（MicroSD 卡槽） | 可插入 MicroSD 卡，适用于需要扩充数据存储空间或备份的应用开发场景。|
| 10  | 3.3 V to 1.5 V LDO（3.3 V 转 1.5 V LDO） | 摄像头的电源转换器，输入 3.3 V，输出 1.5 V。|
| 11  | 3.3 V to 2.8 V LDO （3.3 V 转 2.8 V LDO） | 摄像头的电源转换器，输入 3.3 V，输出 2.8 V。|
| 12  | USB Port（USB 接口） | Micro-USB 接口，可用作开发板的 5 V 供电接口，也可作为通信接口，通过 GPIO19 和 GPIO20 与芯片通信。|
  13  | Battery Soldering Points（电池焊点） | 可以焊接电池母座插头，用于外接锂电池，与 USB 供电二选一。请使用带有保护电路板和电流保险器组件的锂电池。建议电池规格：容量 >1000 mAh, 输出电压 3.7 V， 输入电压 4.2 V – 5 V。|
| 14  | Battery Charger Chip（电池充电芯片）     | 1 A 线性锂电池充电器 (ME4054BM5G-N)，采用 ThinSOT 封装。充电电源来自 **USB 接口**。|
| 15  | Battery Red LED（电池指示红灯）          | 开发板连接 USB 电源，不接电池的情况下，红灯闪烁。接电池状态下，电池充电正在进行时，红灯亮；电池充电完成后，红灯灭。 |
| 16  | Accelerometer（加速度传感器）            | 三轴加速度传感器 (QMA7981)，用于屏幕旋转等使用场景。|

## 1.5. ESP32-S3-EYE-SUB 子板组件

<center>

| ESP32-S3-EYE-SUB - 正面和背面 | 
|:--:| 
|ESP32-S3-EYE-SUB - 正面和背面|

</center>

下面从 LCD 显示屏开始逆时针依次介绍子板正面和背面的主要组件。

| 主要组件| 介绍 |
|---|----|
| LCD Display（LCD 显示屏） | 1.3” LCD 显示屏，通过 SPI 总线连接芯片。 |
| Strapping Pins（Strapping 管脚） | 从主板引出的四个 strapping 管脚，空闲管脚测试点。|
| Female Headers（排母） | 连接主板上的排针。 |
| LCD FPC Connector（LCD FPC 接口）  | 通过 FPC 排线连接子板和 LCD 显示屏。 |
| LCD_RST | LCD_RST 测试点。您可以通过控制信号重启 LCD 显示屏。|

## 1.6. 内含组件和包装

### 1.6.1. 零售订单

如购买样品，每个开发板将以防静电袋或零售商选择的其他方式包装。每个包装内含：

-  1 块 ESP32-S3-EYE-MB 主板
-  1 块 ESP32-S3-EYE-SUB 子板

主板和子板出厂时已组装好。

零售订单请前往 <https://www.espressif.com/zh-hans/company/contact/buy-a-sample>。

### 1.6.2. 批量订单

如批量购买，开发板将以大纸板箱包装。

批量订单请前往 <https://www.espressif.com/zh-hans/contact-us/sales-questions>。

## 1.7. 默认固件和功能测试

ESP32-S3-EYE 出厂即烧录[默认固件](https://github.com/espressif/esp-who/tree/master/default_bin/esp32-s3-eye) ，方便您立即上手使用开发板，体验语音唤醒、语音命令识别、人脸检测和识别的功能。

使用开发板前，您需要准备以下硬件：

-  1 套 ESP32-S3-EYE 开发板
-  1 根 USB 2.0 数据线（标准 A 型转 Micro-B 型），为开发板接入电源

通电前，请确保开发板完好无损，主板与子板已组装好。然后按照以下步骤开始使用开发板：

1. 使用 USB 数据线连接开发板的 **USB 接口**与电源。开发板上电期间会有如下反应：

* **模组电源指示灯**亮起并保持几秒钟，说明默认固件正在加载。
* **模组电源指示灯**熄灭，说明默认固件加载完成。开发板默认进入人脸识别模式。
* LCD 显示屏播放实时画面。

现在，开发板已准备好等待执行命令。有两种方式操作开发板：物理按键或语音指令。下面先介绍通过物理按键操作开发板。

2. 面对摄像头，显示屏上出现整张人脸，开发板开始检测人脸。检测到人脸后，显示屏上出现蓝色方框。
3. 按下 **MENU** 键，开发板为检测到的人脸录入 ID（从 1 开始）。
4. 按下 **UP+** 键，开发板进行人脸识别。若识别到之前检测并录入的人脸，显示屏上出现相应的人脸 ID；若无法识别，显示屏上出现 "WHO?"（谁？）。
5. 按下 **PLAY** 键，删除最新录入的人脸 ID，显示屏上出现 "XXX ID(S) LEFT"（剩 XXX 个 ID）。

下面介绍通过语音指令操作开发板：

1. 重复上面步骤 1。
2. 说出中文唤醒词“Hi 乐鑫”唤醒开发板。唤醒后，**模组电源指示灯**亮起，说明开发板在等待语音指令。
3. 说出中文命令词，命令词识别成功后**模组电源指示灯**会闪烁，等待开发板执行命令。在人脸识别模式下，默认固件支持的中文命令词见下表。

| 默认固件支持的中文命令词 | 设备反馈  |
|---|---|
| 添加人脸 | 开发板录入人脸 ID |
| 识别一下 | 开发板显示识别到的人脸 ID。若无法识别，则显示 "WHO?"（谁？）。 |  
| 删除人脸 | 开发板删除最新录入的人脸 ID，显示 "XXX ID(S) LEFT"（剩 XXX 个 ID）。|

4. 您也可以在执行完步骤 2 唤醒开发板后通过命令词切换开发板的工作模式，命令词识别成功后**模组电源指示灯**会闪烁。不同工作模式的命令词见下表。

| 不同工作模式的命令词 | 设备反馈 |
|---|---|
| 人脸识别 | 开发板若检测到人脸，则显示蓝色方框。|  
| 移动侦测 | 开发板若检测到物体移动，则左上角显示蓝色实心方框。|
| 仅显示 | 开发板仅显示摄像头拍摄的实时画面。 |
| 停止工作 | 开发板停止工作，仅显示乐鑫标志。 |

至此您已经体验了开发板的主要功能。下面的章节将说明如何在开发板上烧录固件、硬件资源和相关文档等。

# 2. 开始开发应用

本小节介绍如何在开发板上烧录固件以及相关准备工作。

## 2.1. 必备硬件

-  1 套 ESP32-S3-EYE 开发板
-  1 根 USB 2.0 数据线（标准 A 型转 Micro-B 型），用于为开发板接入电源，并向开发板烧录固件
-  1 台电脑（Windows、Linux 或 macOS）

## 2.2. 可选硬件

-   1 个 MicroSD 存储卡
-   1 块锂电池
-   1 套[3D打印外壳](#55-3D打印外壳)

> **注意**
>
> 请使用带有保护电路板的锂电池。

## 2.3. 硬件设置

使用 USB 数据线连接开发板的 **USB 接口**与电源，**模组电源指示灯**应亮起。如果未接入电池，则**电池指示红灯**闪烁。

硬件设置已完成，按照下列步骤配置软件。

## 2.4. 软件设置

准备开发工具，请前往 [ESP-WHO](https://github.com/espressif/esp-who/blob/master/README_CN.md) 文档查看以下步骤：

1. [获取 ESP-IDF](https://github.com/espressif/esp-who/blob/master/README_CN.md#获取-esp-idf)，配置基于 ESP32-S3 的 C 语言 PC 开发环境。
2. [获取 ESP-WHO](https://github.com/espressif/esp-who/blob/master/README_CN.md#获取-esp-who)，运行乐鑫图像处理开发框架。
3. [运行 ESP-WHO 示例](https://github.com/espressif/esp-who/blob/master/README_CN.md#运行示例)。

# 3. 硬件参考

本小节介绍有关开发板硬件的更多信息。

## 3.1. GPIO 分配

除了 GPIO3 可用于配置 LED 灯组合状态，**ESP32-S3-WROOM-1** 模组上的其他 GPIO 均已用于控制开发板的组件或功能。如果您想自己配置管脚，请参考[相关文档](#5-相关文档)部分提供的原理图。

## 3.2. 独立的模组与摄像头供电电路

ESP32-S3-EYE 开发板为摄像头和 ESP32-S3-WROOM-1 模组及其他器件提供独立电源，这样可以减少模组电路上音频信号对摄像头电路的干扰，提高开发板的整体性能。

<center>

|ESP32-S3-EYE - 模组供电电路| 
|:--:| 
|ESP32-S3-EYE - 模组供电电路|

</center>

<center>

|ESP32-S3-EYE - 摄像头供电电路| 
|:--:| 
|ESP32-S3-EYE - 摄像头供电电路|

</center>

# 4. 硬件版本

## 4.1. 改版历史

ESP32-S3-EYE v2.2 相对于 ESP32-S3-EYE v2.1 在硬件方面有两处变更：1) 主板丝印，2) 主板增加限流电阻；固件方面一处变更：增加对英文唤醒词和英文命令词的支持（具体见[[英文版本文档]](../../en/get-started/ESP32-S3-EYE_Getting_Started_Guide.md)）。

硬件方面的变更具体如下：

1.  主板丝印（背面）：ESP32-S3-EYE v2.2 的主板丝印为 ESP32-S3-EYE-MB_V2.2，ESP32-S3-EYE v2.1 的主板丝印为 ESP32-S3-EYE-MB_V2.1。

| ESP32-S3-EYE v2.2 主板丝印 | ESP32-S3-EYE v2.1 主板丝印 |
|---|----|
|  ESP32-S3-EYE v2.2 主板丝印 |ESP32-S3-EYE v2.1 主板丝印 |

2.  ESP32-S3-EYE v2.2 的主板增加限流电阻 R83，防止用户误上拉 GPIO3 而烧坏**模组电源指示灯**。

| ESP32-S3-EYE v2.2 限流电阻 R83 位置 | ESP32-S3-EYE v2.1 无限流电阻 R83  |
|---|----|
|  ESP32-S3-EYE v2.2 限流电阻 R83 位置 |ESP32-S3-EYE v2.1 无限流电阻 R83 |

3.  因主板丝印变更和增加限流电阻同步更新**主板原理图**、**主板 PCB 布局图**、**主板尺寸图**、**主板尺寸图源文件**（见[相关文档](#5-相关文档)小节提供的文件）。

## 4.2. 已知问题

ESP32-S3-EYE 没有 USB 至 UART 桥接器，可能会出现已烧写的程序不停重启时无法再烧写程序的情况。

如果出现这个问题，您需要：

1. 按住 BOOT 键再按住 RST 键，然后松开 RST 键，再松开 BOOT 键，然后开发板进入下载模式，开始下载程序。
2. 下载完成后再按下 RST 键启动程序。

# 5. 相关文档

## 5.1. 技术规格书

-   [ESP32-S3 技术规格书](https://www.espressif.com/sites/default/files/documentation/esp32-s3_datasheet_cn.pdf) (PDF)
-   [ESP32-S3-WROOM-1 & ESP32-S3-WROOM-1U 技术规格书](https://www.espressif.com/sites/default/files/documentation/esp32-s3-wroom-1_wroom-1u_datasheet_cn.pdf) (PDF)

## 5.2. 原理图

-   [ESP32-S3-EYE-MB v2.2 主板原理图](https://dl.espressif.com/dl/schematics/SCH_ESP32-S3-EYE-MB_20211201_V2.2.pdf) (PDF)
-   [ESP32-S3-EYE-MB v2.1 主板原理图](https://dl.espressif.com/dl/schematics/SCH_ESP32-S3-EYE-MB_20210913_V2.1.pdf) (PDF)
-   [ESP32-S3-EYE-SUB 子板原理图](https://dl.espressif.com/dl/schematics/SCH_ESP32-S3-EYE_SUB_V1.1_20210913.pdf) (PDF)

## 5.3. PCB 布局图

-   [ESP32-S3-EYE-MB v2.2 主板 PCB 布局图](https://dl.espressif.com/dl/schematics/PCB_ESP32-S3-EYE_MB_V2.2_20211201.pdf) (PDF)
-   [ESP32-S3-EYE-MB v2.1 主板 PCB 布局图](https://dl.espressif.com/dl/schematics/PCB_ESP32-S3-EYE_MB_V2.1_20210913.pdf) (PDF)
-   [ESP32-S3-EYE-SUB 子板 PCB 布局图](https://dl.espressif.com/dl/schematics/PCB_ESP32-S3-EYE_SUB_V1.1_20210913.pdf) (PDF)

## 5.4. 尺寸图

-   [ESP32-S3-EYE-MB v2.2 主板正面尺寸图](https://dl.espressif.com/dl/schematics/DXF_ESP32-S3-EYE_MB_top_V2.2_20211207.pdf) (PDF)
-   [ESP32-S3-EYE-MB v2.1 主板正面尺寸图](https://dl.espressif.com/dl/schematics/DXF_ESP32-S3-EYE_MB_top_V2.1_20211111.pdf) (PDF)
-   [ESP32-S3-EYE-MB v2.2 主板背面尺寸图](https://dl.espressif.com/dl/schematics/DXF_ESP32-S3-EYE_MB_Bottom_V2.2_20211207.pdf) (PDF)
-   [ESP32-S3-EYE-MB v2.1 主板背面尺寸图](https://dl.espressif.com/dl/schematics/DXF_ESP32-S3-EYE_MB_Bottom_V2.1_20211111.pdf) (PDF)
-   [ESP32-S3-EYE-SUB 子板尺寸图](https://dl.espressif.com/dl/schematics/DXF_ESP32-S3-EYE_SUB_V1.1_20211111.pdf) (PDF)
-   [ESP32-S3-EYE-MB v2.2 主板正面尺寸图源文件](https://dl.espressif.com/dl/schematics/DXF_ESP32-S3-EYE_MB_top_V2.2_20211207.dxf) (DXF) - 可使用 [Autodesk Viewer](https://viewer.autodesk.com/) 查看
-   [ESP32-S3-EYE-MB v2.1 主板正面尺寸图源文件](https://dl.espressif.com/dl/schematics/DXF_ESP32-S3-EYE_MB_top_V2.1_20211111.dxf) (DXF) - 可使用 [Autodesk Viewer](https://viewer.autodesk.com/) 查看
-   [ESP32-S3-EYE-MB v2.2 主板背面尺寸图源文件](https://dl.espressif.com/dl/schematics/DXF_ESP32-S3-EYE_MB_Bottom_V2.2_20211207.dxf) (DXF) - 可使用 [Autodesk Viewer](https://viewer.autodesk.com/) 查看
-   [ESP32-S3-EYE-MB v2.1 主板背面尺寸图源文件](https://dl.espressif.com/dl/schematics/DXF_ESP32-S3-EYE_MB_Bottom_V2.1_20211111.dxf) (DXF) - 可使用 [Autodesk Viewer](https://viewer.autodesk.com/) 查看
-   [ESP32-S3-EYE-SUB 子板尺寸图源文件](https://dl.espressif.com/dl/schematics/DXF_ESP32-S3-EYE_SUB_V1.1_20211111.dxf) (DXF) - 可使用 [Autodesk Viewer](https://viewer.autodesk.com/) 查看

## 5.5. 3D打印外壳

以下的3D模型是一个由两部分组成的外壳，您可以为您的ESP32-S3-EYE 3D打印出来。请注意，所有3D打印产品会有公差差异。您的成功记录可能会有所不同。

- [ESP32-S3-EYE 上壳](../../_static/get-started/ESP32-S3-EYE_3dpcase_top.STL)
- [ESP32-S3-EYE 下壳](../../_static/get-started/ESP32-S3-EYE_3dpcase_btm.STL)

<center>

|ESP32-S3-EYE - 外壳 在拓竹P1S上3D打印| 
|:--:| 
|ESP32-S3-EYE - 外壳 在[拓竹P1S上3D打印](https://bambulab.cn/zh-cn/p1)|

</center>

有关本开发板的更多设计文档，请联系我们的商务部门 [<sales@espressif.com>](sales@espressif.com)。

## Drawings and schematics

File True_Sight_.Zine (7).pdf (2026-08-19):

# True Sight

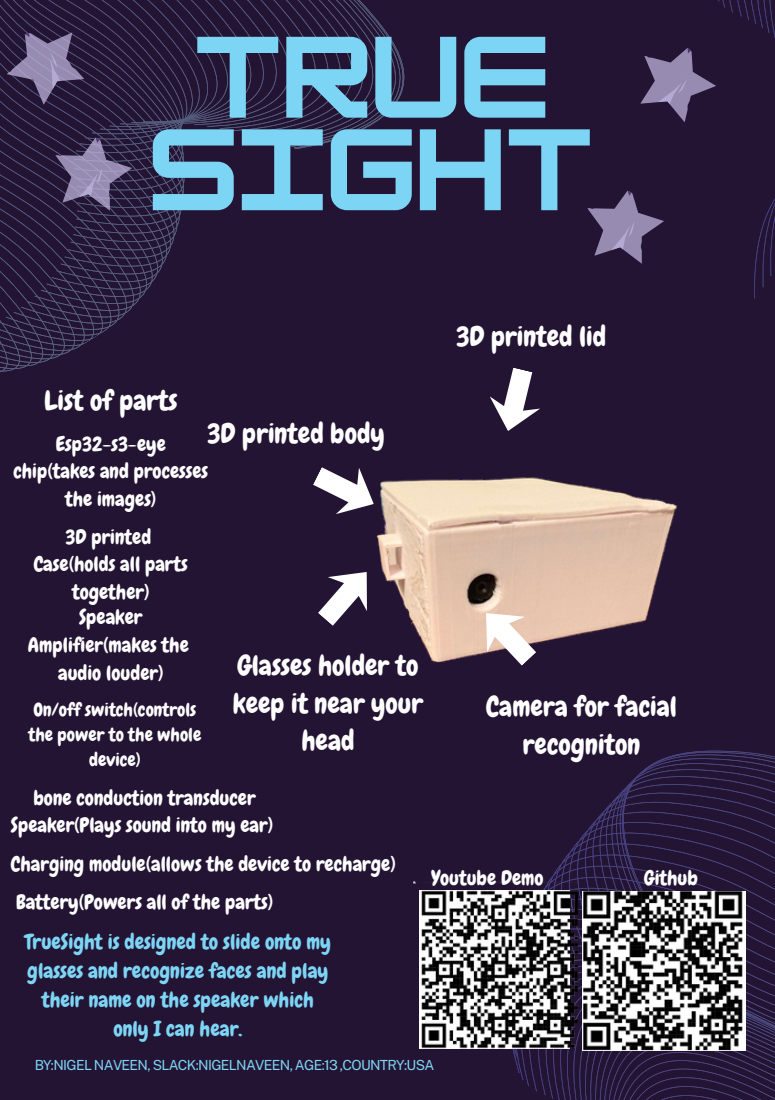
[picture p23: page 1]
Youtube Demo; Github; 3D printed lid; 3D printed body

List of parts
Esp32-s3-eye
chip(takes and processes
the images)
3D printed
Case(holds all parts
together)
Speaker
Amplifier(makes the
audio louder)
On/off switch(controls
the power to the whole
device)
bone conduction transducer
Speaker(Plays sound into my ear)
Charging module(allows the device to recharge)
Battery(Powers all of the parts)
TrueSight is designed to slide onto my
glasses and recognize faces and play
their name on the speaker which
only I can hear.

Glasses holder to
keep it near your
head

Camera for facial
recogniton

BY:NIGELNAVEEN,SLACK:NIGELNAVEEN,AGE:13,COUNTRY:USA

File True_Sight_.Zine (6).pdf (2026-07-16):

# True Sight

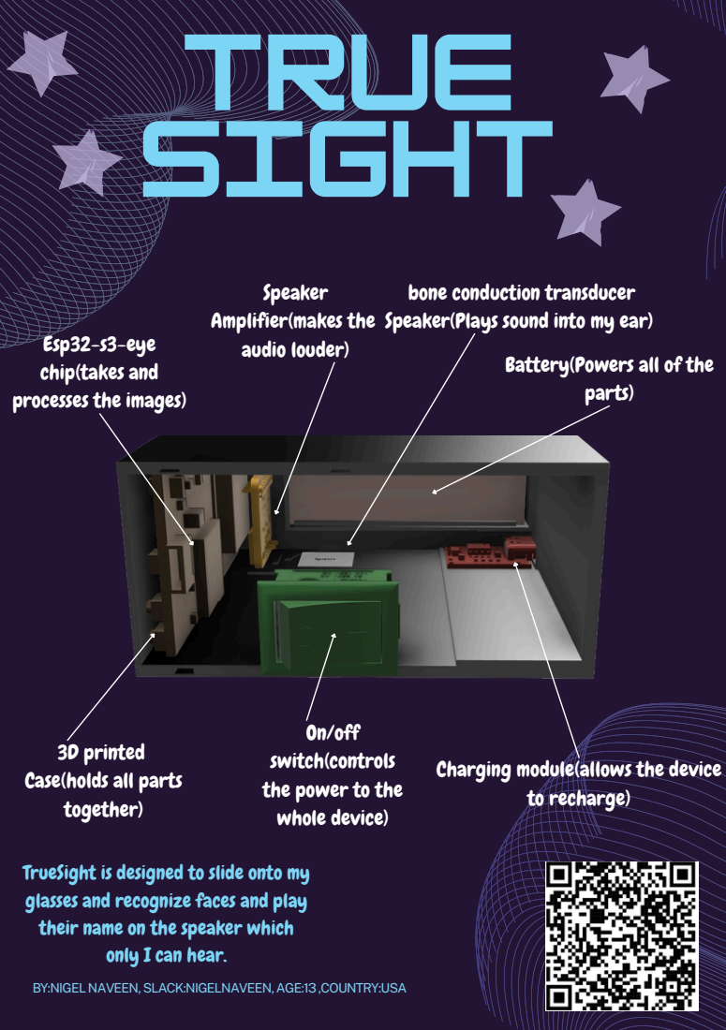
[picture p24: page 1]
to recharge)

Speaker
Amplifier(makes the
audio louder)

bone conduction transducer
Speaker(Plays sound into my ear)

Esp32-s3-eye
chip(takes and
processes the images)

Battery(Powers all of the
parts)

On/off
switch(controls
the power to the
whole device)

3D printed
Case(holds all parts
together)

Charging module(allows the device

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

BY:NIGELNAVEEN,SLACK:NIGELNAVEEN,AGE:13,COUNTRY:USA

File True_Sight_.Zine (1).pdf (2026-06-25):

# True Sight

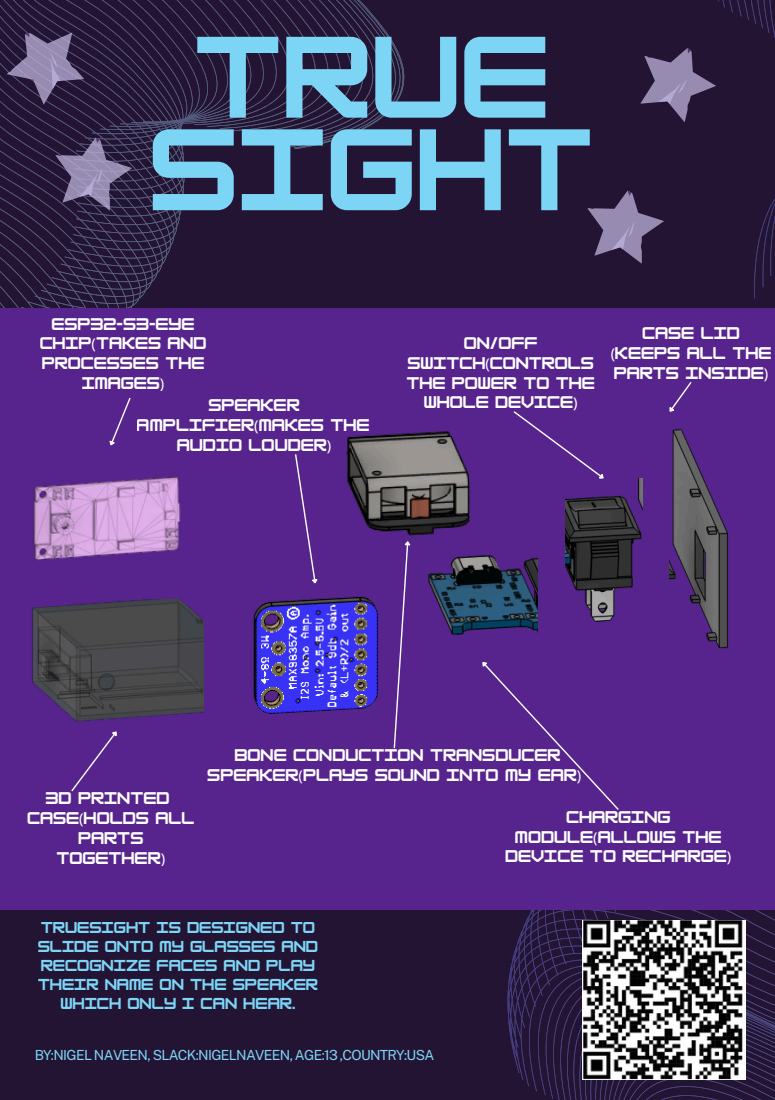
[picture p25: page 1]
Speaker(Plays sound into; my ear); Speaker; On/off switch(controls; the; power to the; whole device)

Esp32-s3-eye
chip(takes and
processes the
images)

Case lid
(keeps all the
parts inside)

Amplifier(makes the
audio louder)

bone conduction transducer

3D printed
Case(holds all
parts
together)

Charging
module(allows the
device to recharge)

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

BY:NIGELNAVEEN,SLACK:NIGELNAVEEN,AGE:13,COUNTRY:USA

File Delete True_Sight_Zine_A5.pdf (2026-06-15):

# True Sight

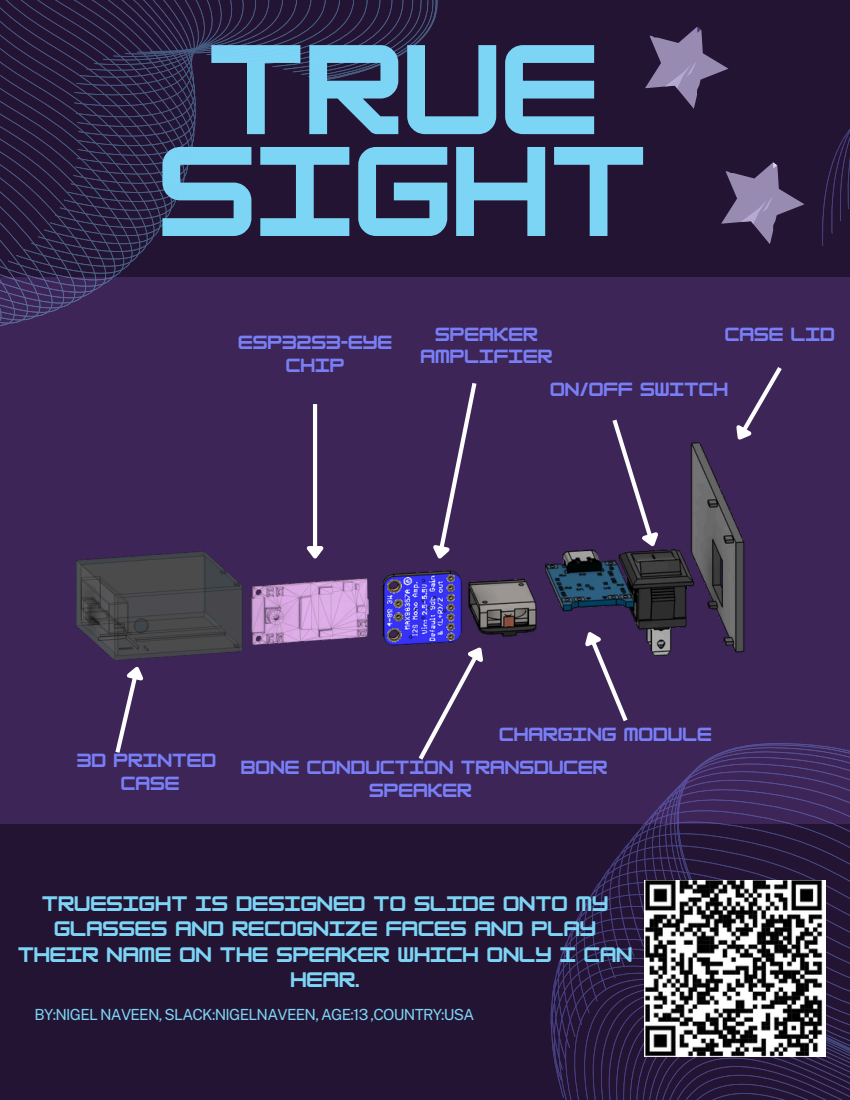
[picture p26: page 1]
Case lid; 3D printed Case; Esp32s3-eye chip; Speaker; Speaker Amplifier; Charging module; hear.

On/off switch

bone conduction transducer

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

BY:NIGELNAVEEN,SLACK:NIGELNAVEEN,AGE:13,COUNTRY:USA

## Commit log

2026-05-24 Delete True Sight BOM - Sheet1.csv
    Going to replace it with a more complete version
    [True Sight BOM - Sheet1.csv]
2026-05-24 Update README.md
    I added a screenshot of the BOM but NOT all of it
2026-05-25 Added the 3d models
    Added the 3d models to the repository and I named them after each part.
    [True_Sight_Pins.stl, True_sight_Lid.stl, True_sight_main-body.stl]
2026-06-05 Add files via upload
    Adding the FINAL BOM to the github repo
    [True Sight BOM - Sheet1 (1).csv]
2026-06-05 Rename True Sight BOM - Sheet1 (1).csv to True Sight BOM.csv
    Renaming the file
    [True Sight BOM.csv]
2026-06-05 Update README.md
    Changed the BOM image to have every item there.
2026-06-05 Moving the 3d models to a dedicated folder
    [True_Sight_Pins.stl, True_sight_Lid.stl, True_sight_main-body.stl]
2026-06-15 Rename True Sight BOM - Sheet1 (2).csv to True Sight BOM.csv
    [True Sight BOM.csv]
2026-06-16 Rename True Sight BOM.csv to BOM.csv
    [BOM.csv]
2026-06-16 Renamed 3D models to Cad
    [True_Sight_Pins.step]
2026-06-16 Changing the folder name
    [True_Sight_Lid.step]
2026-06-16 Add esp-who framework folder
2026-06-16 Adding the source code
    [ESP32-S3-EYE_3dpcase_btm.STL, ESP32-S3-EYE_3dpcase_top.STL, partitions.csv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]
2026-06-16 Fixed location of files
    [ESP32-S3-EYE_3dpcase_btm.STL, ESP32-S3-EYE_3dpcase_top.STL, partitions.csv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]
2026-06-25 Rename True Sight BOM - Sheet1 (3).csv to True Sight BOM
2026-06-25 Rename True Sight BOM to True-Sight-BOM.csv
    [True-Sight-BOM.csv]
2026-06-26 Making the lids better
    [True_Sight_Lid.step]
2026-06-26 REMOVE AND RESET
    [True_Sight_Lid.step, True_Sight_Main_Body.step, True_Sight_Pin.step]
2026-07-08 Rename True Sight BOM - Sheet1 (4).csv to True Sight BOM.csv
    [True Sight BOM.csv]
2026-07-08 Rename True Sight BOM - Sheet1 (5).csv to True Sight BOM.csv
    [True Sight BOM.csv]
2026-07-22 Rename True Sight BOM - Sheet1 (6).csv to True Sight BOM.csv
    [True Sight BOM.csv]
